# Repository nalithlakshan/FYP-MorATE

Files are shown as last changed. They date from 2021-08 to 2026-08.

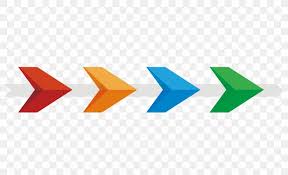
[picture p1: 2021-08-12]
QT Software Project/img/testing3.jpg

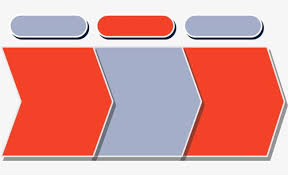
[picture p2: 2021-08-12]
QT Software Project/img/testing4.png

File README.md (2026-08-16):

# FYP-MorATE
This repository contains all the design files and the source codes of an Automated Test Equipment (ATE) for digital IC testing, developed by the final year project group-16 of the ENTC16 batch.

Youtube video link (demonstration): https://www.youtube.com/watch?v=_BMeR-ZwBSQ

Design files and source codes consist of,
* Altium PCB design projects of each individual PCB of the ATE
* QT project of the standalone computer software GUI of the ATE
* Embedded firmware projects of the STM32 microcontrollers in the ATE
* Quartus project of the FPGA digital design for the digital system in the ATE.

## Publication
L. Nawarathna, N. Udugampola, Y. Yasawardhana, T. Weerasinghe and S. Thayaparan, "Low-Cost Automatic Test Equipment for Digital ICs Using DE0-Nano - Altera Cyclone IV FPGA," 2021 3rd International Conference on Electrical, Control and Instrumentation Engineering (ICECIE), Kuala Lumpur, Malaysia, 2021, pp. 1-4, doi: 10.1109/ICECIE52348.2021.9664695.

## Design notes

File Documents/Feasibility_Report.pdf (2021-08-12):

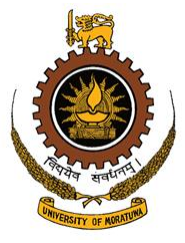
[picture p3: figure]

i

# IC Tester

### Project Proposal and Feasibility Report submitted in partial fulfillment of the

### requirements for the Degree of Bachelor of Science of Engineering in

### The Department of Electronic & Telecommunication Engineering University of

### Moratuwa

Supervisor:

Dr. Thayaparan Subramniam

Group Members:

K.G.L.P.Nawarathna

N.L.Udugampola

W.W.A.T.E.Weerasignhe

N.P.Y.Yasawardhana

ii

## Abstract

IC TESTER

Group members:

K.G.L.P.Nawarathna, N.L.Udugampola, W.W.A.T.E.Weerasignhe, N.P.Y.Yasawardhana

Department of Electronic and Telecommunication Engineering

Supervisor: Dr. Thayaparan Subramniam

Keywords: FPGA, Hardware Architecture, Integrated Circuit, IC Tester, ATE

This report acknowledges a feasibility study of designing, prototyping, and testing an IC tester.

The scope of this project basically covers development of a standalone computer software with

GUI, digital design and implementation of digital IO driving unit, hardware design of electrical

measuring instruments, power sources etc. Finally, the complete task is intended to be prototyped

and basic tests like IDDQ test, continuity test, scan test, boundary scan and etc. will be

implemented and demonstrated on digital ICs.

Current state-of-the-art in IC testing consists of very high-speed digital testing capabilities even

up to 5Gbps, highly parallel testing capabilities along with automation in all possible areas.

Teradyne, Advantest, LTX-Credence are some leading commercial vendors of Automatic Test

Equipment (ATE). Price of an ATE tester from such a vendor is millions of dollars.

Ultimate motive of this project is to start IC testing in Sri Lanka. This first step of developing a

locally made IC tester would create new business opportunities within the country. This report

emphasizes that it is feasible to continue this project

iii

## Table of Contents

iv

v

## Table of Figures

vi

## List of Tables

vii

## Acronyms and Abbreviations

IC | Integrated Circuit
VLSI | Very Large-Scale Integration
ATE | Automatic Test Equipment
DUT | Device Under Test
MCU | Microcontroller Unit
UART | Universal Asynchronous Receiver-Transmitter
USB | Universal Serial Bus
SPI | Serial Peripheral Interface
FPGA | Field Programmable Gate Array

## 1. INTRODUCTION

## 1.1 Introduction of IC Testing

Testing is a step followed in IC fabrication process to ensure the selected device has no

manufacturing defects. In earlier times, IC designers only focused about the speed, area and power

in optimization of the design. In contrast to that nowadays, testability has become the next factor

which decides the quality of a design. According to the VLSI Realization Process the testing is

placed as the process before delivering the chips to the customers.

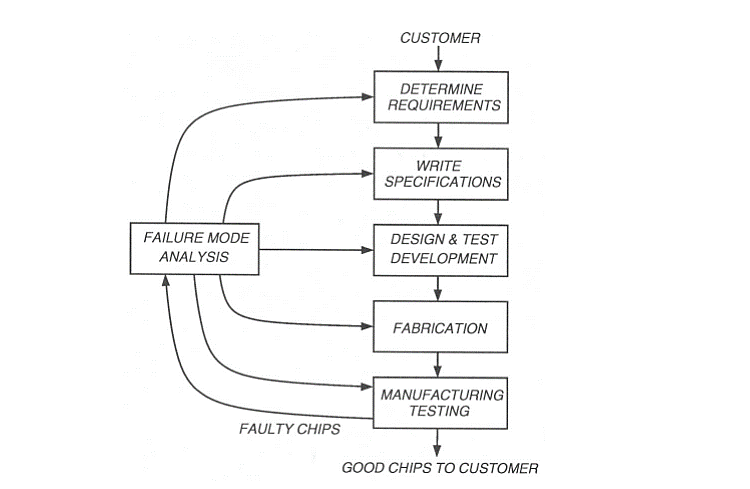
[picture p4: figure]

Figure 1-1 VLSI Realization Process

Generally, ICs are manufactured in large quantities on a single wafer by exposing to the processes

such as photolithography. Before this wafer is cut into pieces in other words which is called as die

preparation, to obtain individual circuits, all the individual circuits are tested for their functional

defects which can be occurred by activities such as misalignment of films, faults with etching

process, faults in materials and impurities. This process is known as Wafer Testing. Then, to

prevent physical damage and corrosion, the dice are placed inside a supporting case. This process

is named as IC packaging. Because there are mechanical and chemical processes involved in

packaging, even after the wafer test is completed successfully, faults in IC can occur. For example,

the bonding wires can be damaged or shorted in encapsulation, die can be misaligned and mutual inductance and capacitance can appear. Therefore, it is essential to perform tests again before

delivering good chips to the customers.

Both wafer testing and final testing after packaging are conducted by the machines called ATE.

They can perform both Parametric Tests (such as output drive current test, leakage test etc.) and

Functional Tests (check the proper functionality of chip nodes). High end testers consist of three

components which are test head, workstation, and mainframe. Workstation can be identified as the

user interface to the tester. A user can debug an IC through the software packages included in the

workstation. Mainframe serves as the unit which includes parts such as measuring instruments,

power supplies, digital driver unit etc. The test head contains more sensitive equipment which

needs less distance to the DUT. Some of the ATE machines manufactured by commercial vendors

are as follows

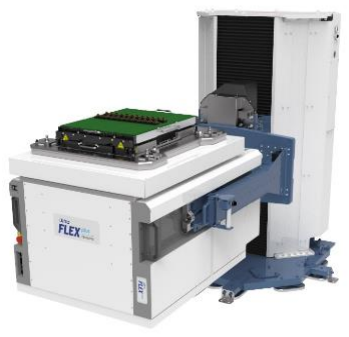
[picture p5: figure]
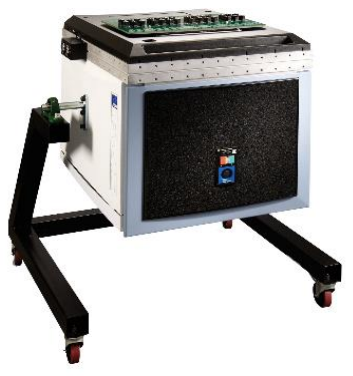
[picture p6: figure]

Figure 1-2 Teradyne UltraFLEXplus | Figure 1-3Teradyne J750Ex-HD Family
- 2.2Gbps digital performance ● 512 digital channels per instrument ● 256 Power supply channels | ● 400 Mbps digital performance ● 2048 multifunction pins ● Parallel IC testing capability
Price – Approximately $2 Million | Price – starting from $99,000

## 1.2 The Problem Statement

IC manufacturers perform tests within their manufacturing plant or outsource the chips to other

companies who carry out the procedure. Since the chips are tested by high end testers, similar to the ATE machines mentioned above, it costs a considerable amount of money for the procedure.

A company which facilitates the IC testing process can be considered as a successful business in

the silicon industry.

Currently in Sri Lanka, ATE machines are not available to perform tests for ICs. It would be an

immense opportunity for the electronic industry in the country as well as a door opening for job

market if an IC tester can be manufactured in Sri Lanka.

## 1.3 Primary Objectives

Primary objectives of this project can be listed as follows.

1. Design and prototype a low cost scaled down hardware software solution for digital IC

testing

The IC tester is expected to test the packaged digital ICs and the design is

exclusive of automatic probers and handlers. A user can program the IC tester

with the user interface provided.

2. Demonstrate the functionality with basic tests for selected packages of digital ICs

Tests such as continuity test, Iddq test and scan test are planned to be performed for

multiple IC packages i.e. DIP14, DIP16, DIP28.

3. Taking the first step to develop a Sri Lanka made IC tester

IC testers are not available in the current electronic industry in Sri Lanka.

Manufacturing such a tester can be a good business opportunity for sub-contracting

IC test process inside the country. The tester expected to develop in this project has

compromised functionality of an industrial scale tester but, with improvements in

future it can be brought out as an industrial scale IC tester.

## 1.4 Scope

There are mainly 5 areas where the scope of this project can be categorized.

1. Standalone cross platform computer software with GUI

This software provides the interface between the tester hardware and the user. It is

based on QT C++ framework, embedded SQLite Database Management System

and a USB interface with the tester hardware.

2. Embedded firmware development

Data transfer and signal control between the computer software package, digital

driver unit and pin cards are handled by the STM32 MCUs. Protocols such as

UART, USB and SPI are expected to be included in the firmware.

3. Digital design and logic driving unit

This unit will be implemented as an FPGA design with Verilog. Up to 20Mbps data

rate will be maintained in the 128 I/O ports. Maximum parallel capability will be

32 inputs and 32outputs at a time.

4. Hardware Designing and Prototyping

Multiple programmable power supply units will be included with various voltage

ranges, current limits, and resolution.

Ex: 0-5V power supply with 1.5A current limit and 10mV resolution

Programmable current source is expected to be designed for the tester. A voltmeter

with milli Volt range and a current measuring unit capable of measuring up to nano

Ampere range are included. Although the complete design will contain 16 pin

cards, for the prototype 2 pin cards will be added including the programmable

switching and routing circuitry and power and control circuitry.

5. Implementing basic tests on suitable ICs.

Following tests are planned to establish in the tester. Continuity testing, Iddq

testing, Scan testing, Boundary scan testing, Functional testing and Bypass Testing.

DIP14, DIP16, DIP28/ DIP40, SOC16, QFP/ TQFP/ LQFP48 are the IC packages

planned to be tested for demonstration.

## 1.6 Uniqueness and National Importance of the Project

The end prototype of this project will be an initiative step to design a Sri Lankan made IC tester.

Since IC testing is not currently an industry in Sri Lanka, this will be a precious opportunity to

start subcontracting in IC testing. In our scope the IC testing is expected to be performed for only packaged ICs. By designing and developing automatic probes and arms and improving the

capability this tester can elevate to wafer testing level.

One of the intentions of this project is to minimize the cost of the product. Powerful IC testers

contain high end instruments such as power supplies, voltmeters purchased and placed off the shelf

from such commercial instrument manufacturers. In our design to minimize the cost in our design,

units such as power supplies and voltmeters are designed by us. Even though it will degrade the

capability of the tester, still selected digital ICs with low complexity can be tested from our tester.

## 1.7 Potential Customers/beneficiaries

The long-term goal of this project is start IC testing in Sri Lanka. The end product of this project

can be considered as the first leap of IC testing in the country and with the time being by adding

sufficient amount of equipment and knowledge, a commercial IC testing service can be formed in

Sri Lanka.

This IC tester can also be sold in the market as a commercial product specially for part suppliers

who handle low quantity custom made ICs and low volumes of FPGA chips programmed with

custom digital designs.

E.g. oscilloscope manufacturers, telecommunication equipment manufacturer.

Additionally, it is possible to market the product as a test bench for electronic research and

development, repair and maintenance. Electronic sign engineers can be considered as an example

for this customer base.

## 2. LITERATURE REVIEW

## 2.1 Generic Architecture of State-Of-The-Art IC Testers

Automated Test Equipment (ATE) are widely used in the semiconductor industry for

manufacturing testing of ICs. Some popular commercial vendors of ATEs are Teradyne, LTX-

Credence, Advantest, etc.

A high-performance tester with a fully upgraded configuration may cost around two million dollars

in average. Targeting only s specific class of devices with designs for testability, a test system with

a reduced configuration can be bought for a price as low as hundred thousand dollars. Probers and

handlers which handles the automation of picking, placing and probing may cost about half a

million dollars additionally.

### 2.1.1 Major Components of High-end ATE testers

- Test head
- Workstation
- Mainframe

Workstation is the computer providing a

user interface to the tester. Test programs are

written, executed and debugged from the

workstation with the tools provided by ATE

vendor. When tester is used in a production

line, workers can control and monitor its day-

to-day operations using the workstation.

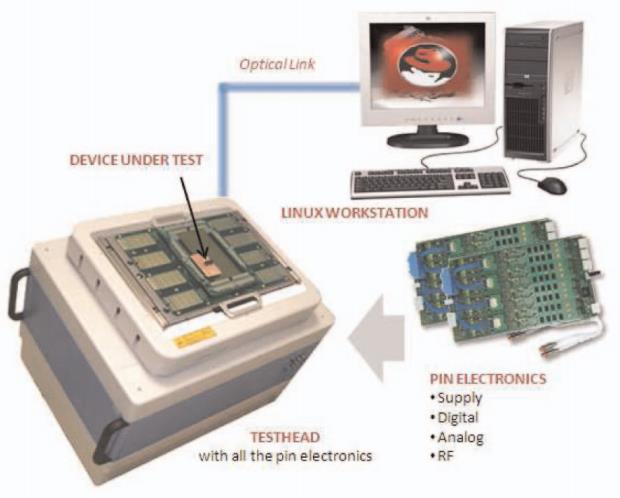
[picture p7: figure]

Mainframe consists of all the major internal hardware of the tester such as measuring instruments,

power supplies, current sources, loads, switching and control circuitry, etc. It normally has separate

subsystems for dc power, digital testing, analog testing, etc. It may also have a robotic manipulator

for positioning of the test head. Normally a refrigeration system providing coolants to regulate the

temperature is also there.

Test head contains highly sensitive test equipment that require close proximity to the device been

tested. Mostly the measuring instruments that need to be right at the pins or pads of the device

Figure 2-1 Major Components of an ATE tester under test (DUT) are there in test head. For example, digital I/O data streams with high speed

require shorter electrical paths between the I/O pins of the DUT and the IO driving ports of the

tester. That is why digital drivers of ATE testers are normally located in the test head.

### 2.1.2 DUT Interfacing

Device Interface Board (DIB) provides electrical connections between the ATE and the DUT.

Depending on the ATE vendor’s technology some other names are also commonly used for the

DIB such as swap block, performance board, family board, etc. Shape and size may differ from

DIB to DIB, but all of their main purpose is to provide a socketed electrical connection between

the test instruments of the ATE and the pins or pads of the DUT.

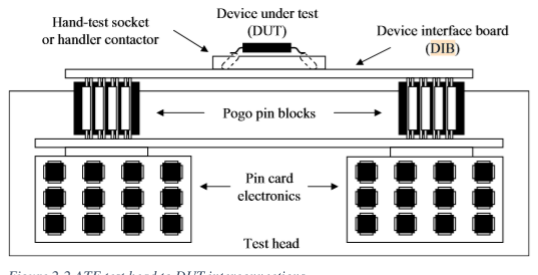
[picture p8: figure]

Following Alternative methods are also used in interfacing the ATE with the DUT.

- Wafer Probers
- Handlers (for packaged devices/ ICs)
- Focused Ion Beams
- Focused Temperature Systems, etc.

### 2.1.3 Tester Hardware Architecture

ATE comprised of following hardware units.

- General purpose voltage/current sources
- Voltage, current measuring instruments
- Switching matrices
- Digital pin cards

Figure 2-2 ATE test head to DUT interconnections

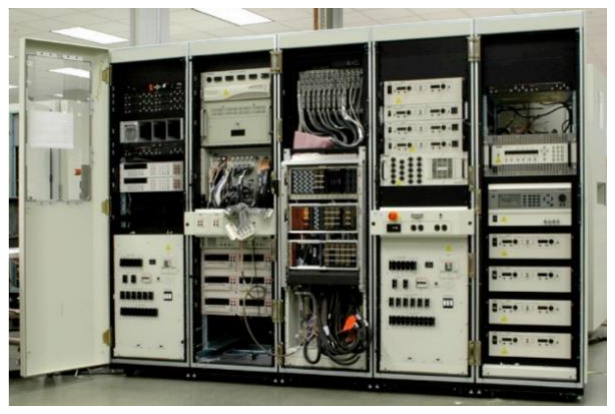
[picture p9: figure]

Figure 2-3 Hardware inside an ATE

- Arbitrary waveform generator and waveform digitizer
- Time measurement system
- RF subsystem
- Computing hardware

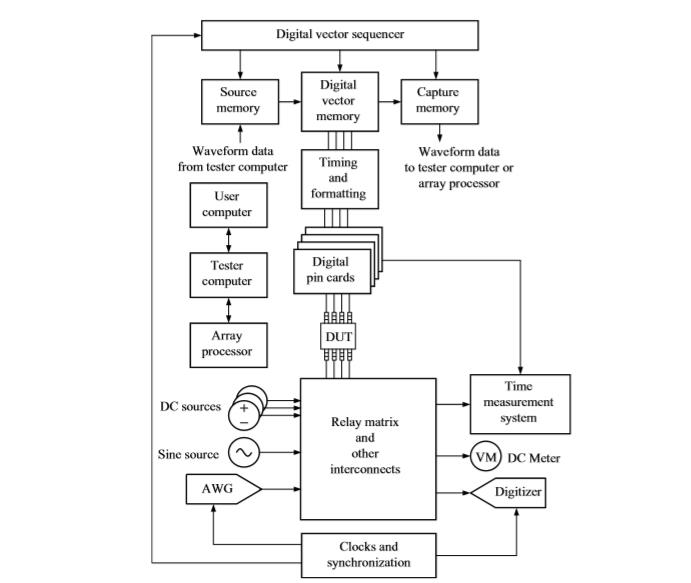
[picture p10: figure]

### 2.1.4 Test Flow

Following diagram shows a general flow chart of testing an IC which starts with continuity testing.

The continuity check simply measures the voltage across the protection diodes of the DUT pins,

by forcing a small current, in order to make sure that the DUT is well connected to the tester. Then

one after another different functional tests, DC tests, AC tests, digital tests are performed to the IC

Figure 2-4 Generic ATE architecture being tested. In each stage if a test is failed the IC is rejected. Both good and bad ICs are sorted in

to bins.

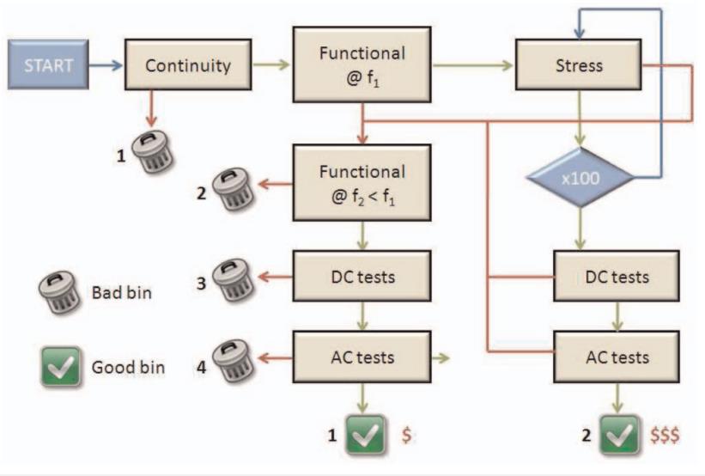
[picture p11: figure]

Figure 2-5 Example of Test Flow

## 2.2 Alternative Methodologies of Testing

Apart from high-end ATE testers used in manufacturing testing in IC fabrication, there are other

methodologies which can be used to test ICs but with different purposes like below.

- Test equipment for manually performed electronic test and repair (mainly for PCBs,

soldered components)

- Combinational logic level handheld IC testers and IC detectors

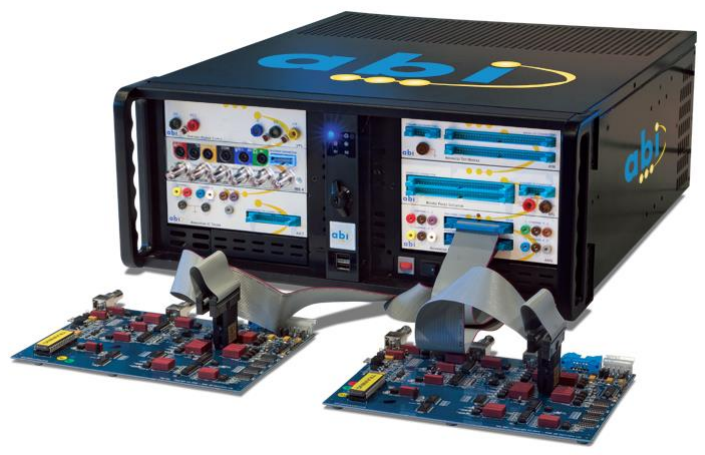
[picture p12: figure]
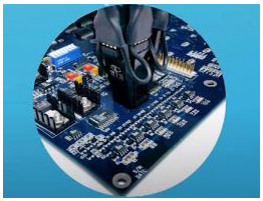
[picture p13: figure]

Figure 2-6 Probing soldered components for testing | Figure 2-7 PCB testing test equipment for R&D purposes

Following figure shows how testing R&D purposes is performed in an industrial environment.

A test module aimed

at testing all digital

ICs and PCBs from all

logic families.

Multiplex matrix

switch with a

16x16 switch

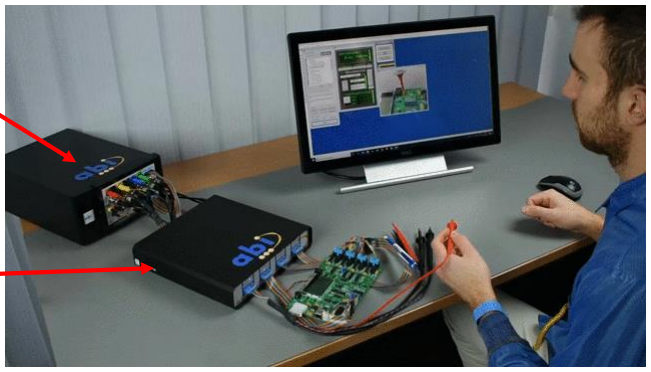
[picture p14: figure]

matrix interface | Figure 2-8 R&D Level Testing

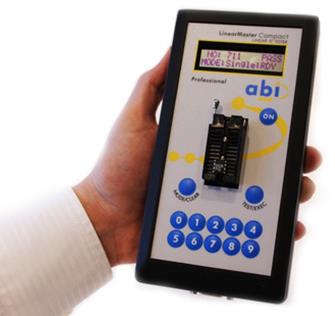
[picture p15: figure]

Figure 2-10 A hand-held IC Tester

This picture shows LinearMaster Compact

Professional by Abi Electronics which is a

handheld IC tester which can do simple logic

testing for ICs with up to 16 pins. It has a large

embedded database to detecting unknown ICs as

well.

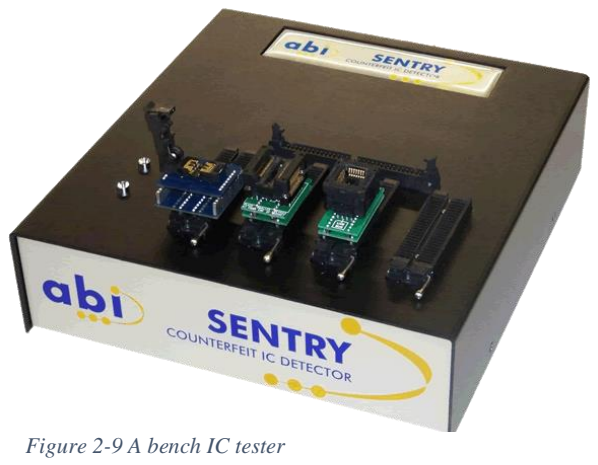
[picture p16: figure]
Figure 2-9 A bench IC tester

Sentry Counterfeit IC Detector by Abi

Electronics is a larger version of the previous

one which has 256 test channels. Apart from

identifying unknown ICs it can easily detect

missing or incorrect dies, lack of bond wires,

inaccurate pinouts and pin impedance

variations. Simple pass or fail results are

returned after testing.

## 3. METHODOLOGY

## 3.1 Project Architecture

### 3.1.1 Block Diagram

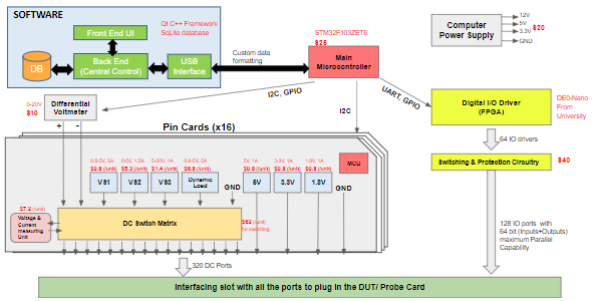
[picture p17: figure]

IC Tester Software is developed as a stand-alone desktop application using Qt framework with

backend in C++ language. Moreover, this software is the top level of the control hierarchy of the

IC tester. Front end UI is made as a Qt widget application. In the backend, the input data from the

user interface which are recorded in the database are converted to a format comprehensible by the

main microcontroller. SQLite is used as the DBMS for this desktop application. USB serial

communication is used to communicate between the desktop application and the STM32

microcontroller.

Main Microcontroller (STM32F103VET6) is the main control unit inside IC tester hardware. It

retrieves commands from the computer software via USB serial communication and then the

received data packets are decoded in order to understand the commands. Then according to those

commands, the main microcontroller delegates tasks to each individual hardware units of the

whole tester.

Figure 3-1 Block diagram of the project architecture

Digital I/O Driver, protection and switching circuitry is the digital subsystem of the tester

which mainly consists of 2 FPGAs, one for sourcing digital data to input pins of the DUT and the

other for capturing digital data from output pins of the DUT. These two FPGAs have 32 digital

drivers each which make the maximum parallel capability of the tester up to 32 bit. Furthermore,

the FPGAs have the ability to change the clock speed as desired.

The interfacing I/O pins of the FPGA goes through protection and switching circuitry. A single

I/O driver is connected to 2 digital I/O ports of the tester via relays, one with 3.3-5V logic

conversion.

Pin cards used in the tester are pluggable based on the requirement where 16 such cards are used

in total having 20 DC interfacing ports each. Hence the total number of ports of the IC Tester sums

to 320 ports. Out of the 20 DC pins in each pin card, 16 pins are multipurpose because they are

switchable through a DC switch matrix and the other 4 pins are directly connected to fixed voltage

sources. Voltage and currents of each individual pin can be measured with the voltage and current

measuring unit in each of the cards. All the relays, multiplexers and shift registers are controlled

with a dedicated MCU in the pin card which also communicates with the main MCU of the IC

Tester.

Differential voltmeter is common to all the 16 pin cards so that it can measure voltage between

any 2 ports out of 320 ports in the IC tester.

### 3.1.2 Flow Chart

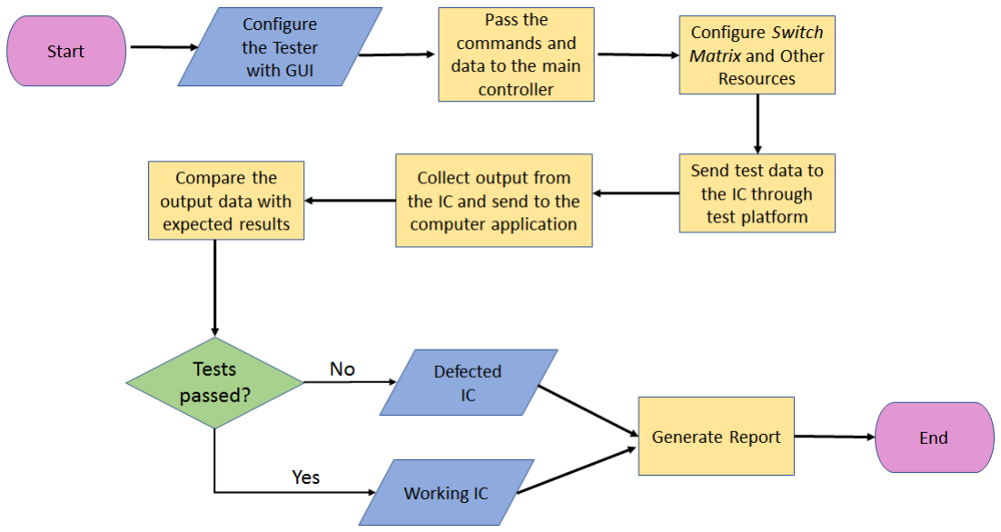
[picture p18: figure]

Figure 3-2 Flow chart of the project architecture

## 3.2 Evaluation of Alternative Methodologies

IC Tester Software framework alternatives

Being more hardware related and more of on-site testing, a standalone desktop application is more

suited than a web or mobile application. Out of the following frameworks suitable for developing

standalone applications, Qt was selected.

Alternative | Pros | Cons
Qt (C++) | Cross-platform C++ more supportive for hardware High community support Better GUI designer, being faster than other languages Good documentation | Complexity to the build process
.Net (C#) | Reliable and simple caching system Large community | Mainly used in windows Memory leaks Limited object-relational support
JavaFX (Java) | Cross-platform Open source Java being the most popular programming language in the world | Not quite mature enough Not very supportive for hardware related projects Comparatively low Performance

Table 1 Alternatives for desktop application frameworks

DBMS alternatives

Out of the following options, SQLite was selected being a serverless (embedded) database that

runs as a part of the application.

Alternative | Pros | Cons
SQLite | Lightweight in setup, administration, and required resource Embedded, server-less database Best suited for standalone apps, specially Qt widget applications | Comparatively smaller library size
PostgreSQL, MySQL | The world’s most advanced open source database Improved security | Requires a DB server Difficult to setup with Qt compared to SQLite

Table 2 Alternatives for Database Management Systems

Power supply units

In making power supplies in the IC tester, we decided to proceed with making our own power

supplies due to the low cost and flexibility.

Alternative | Pros | Cons
Use industrial grade power supplies ($1200 per unit) | High precision and high reliability Wide range of operation Functionality can be monitored through a network | The range of operations exceed the limits of our design. The cost over number of configurable channels is too high.
Use power supply modules | Voltages and currents can be programed | The range of operations exceed the limits of our design. Low programmability
Designing our own Power supplies | Can be designed to match the desired requirements. | Can have design errors.

Table 3 Alternatives for power supply units

Digital I/O driver

Due to the cost effectiveness, we decided to implement our own design with FPGA.

Method | Advantages | Disadvantages
Use source and capture modules | High data rates (ex: 200 MHz) Widely programmable IO levels Built in pattern generators | The cost of a single module is too high (32 bidirectional channel, 2 logic voltage level modules with 10MHz clock -$1600)
Implement our own design with FPGA | Available in the university for initial testing | Limited embedded memory Protections methods are not available for pins (ESD, over voltage, over current)

Table 4 Alternatives for digital I/O drivers

## 3.3 Risk Analysis

Risks | How to overcome?
Limitation of affordable shipping methods due to Covid-19 | Order components from the same supplier, together with the other groups to share shipping cost.
Inability to get together due to Covid-19 | Using online collaboration platforms as much as possible. Ex: Zoom, Atom Teletype, EasyEDA, etc.
Hardware design faults lead to huge additional costs and time. | Every hardware design task is carried out with the collaboration of at least two members. Choosing components by carefully going through datasheets of number of suitable candidates. Going through thorough design verifications.

Risk of a selected component being out of stock

Keep alternative components selected.

Choosing components which are available with 2 selected suppliers (Digi Key, LCSC)

Common resources with the university being unavailable due to other utilizations.

Communication with the relevant labs and do reservations based on requirement.

Table 5 Risk Analysis

## 3.4 Resource requirements and budget

Cost Categories | Total Cost (2 pin card)
Device power supply and wiring | $40
Programmable Power Supply units of the tester | $34
Hardware for switching & routing with a DC matrix | $123
Voltage & Current Measuring Instruments | $31
Hardware for Digital I/O System | $32
Passive Components | $20
Enclosure Cost | $30
PCB cost | $40
Shipping cost | $384
TOTAL | $734

Table 6 Total budget of the project

Since our project is very hardware intensive, electronic components were selected from two

different suppliers (DIGI Key and LCSC) and the budget was prepared mainly with the quotations

of those electronic components which are listed below.

Manufacturer | Man. Part No | Qty | Unit Price | Cost
On Semi | NTMFS4C022NT1G | 17 | $0.261 | $4.437
Omron Electronics | G5NB-1A-E-DC12 | 142 | $0.250 | $35.500
TE Connectivity | 1649222-1 | 36 | $0.350 | $12.600
Texas Instruments | ULN2003A | 24 | $0.120 | $2.880
On Semi | 74HC595 | 24 | $0.114 | $2.736
On Semi | MMBT2222ALT1G | 17 | $0.009 | $0.153
ST Microelectronics | STM32F103C8T6 | 1 | $2.000 | $2.000
Texas Instruments | CD74HC4067SM96 | 3 | $0.470 | $1.410

$61.716

Total for 2 pin cards | $123.43

Table 7 Budget for the major components for DC switching and routing

Manufacturer | Man. Part No | Qty | Unit Price | Cost
Omron Electronics | G5NB-1A-E-DC12 | 8 | $0.250 | $2.000
TE Connectivity | 1649222-1 | 4 | $0.350 | $1.400
Maxim Integrated | MAX4239AUT | 2 | $1.000 | $2.000
Texas Instruments | ADS1115 | 3 | $3.170 | $9.510
Texas Instruments | LMV321 | 2 | $0.170 | $0.340
Texas Instruments | ISO1541DR | 2 | $1.170 | $2.340
Analog Devices (https://lcsc.com/brand-detail/178.html) | REF02CSZ-REEL7 | 2 | $2.081 | $4.162
Analog Devices (https://lcsc.com/brand-detail/178.html) | OP1177 | 4 | $1.547 | $6.118
Texas Instruments | TPL0102 | 2 | $1.760 | $3.520
| | | | $31.390

Table 8 Budget of the major components for measuring instruments and dynamic loads

Manufacturer | Man. Part No | Qty | Unit Price | Cost
Texas Instruments | TPS56528DDAR | 2 | 0.59 | 1.18
Analog Devices | LT3081 | 2 | 5.32 | 10.64
Texas Instruments | TPS54202 | 2 | 0.39 | 0.78
Texas Instruments | TPS7A7001DDAR | 6 | 0.77 | 4.62
Texas Instruments | TPL0102-100RUCR | 10 | 1.417 | 14.17
SXN | HSMS0650-3R3M | 2 | 0.21 | 0.42
TDK | RLF7030T-6R8M2R8 | 2 | 1.009 | 2.018
| | | | $33.828

Table 9 Budget of the major components for power sources

## 3.5 Task Delegation

Preliminary tasks | Digital design and
implementation
Hardware design | Software and
firmware
development

Testing and
prototyping
Task | Nalith | Yasara | Thilina | Lahiru

Literature review and exploring possible methods

Designing programmable power supply units

Designing voltage and current measuring instruments

Designing a programmable dynamic load

Design of hardware for switching and routing in the tester

Hardware design of Digital I/O subsystem

PCB design

Front end software development (standalone GUI)

Backend software development and database management

Communication Interface between the PC and Tester

Firmware development

Digital design of digital I/O subsystem on a FPGA

Hardware prototyping with wiring, soldering, etc.

Electronic testing & debugging of prototypes

Software & firmware testing of prototypes

Documentation

Table 10 Task delegation among the group members

There are 4 major categories of work in the project and all 4 members take part in tasks from all

those 4 categories, for better efficiency and productivity. But major contributions of the members

can be summarized as, Nalith and Yasara more focused on firmware development, software

switching and control while Thilina and Lahiru contributing more for hardware and digital design.

## 3.6 Timeline

Task | Feb | Mar | Apr | May | Jun | Jul | Aug | Sep | Oct | Nov | Dec

Literature review and exploring possible methods

Designing programmable power supply units

Designing voltage and current measuring instruments

Designing a programmable
dynamic load

Design of hardware for switching and routing in the tester

Hardware design of Digital I/O subsystem

PCB design

Front end software development (standalone GUI)

Backend software development and database management

Communication Interface
between the PC and Tester

Firmware development

Digital design of digital I/O subsystem on a FPGA

Hardware prototyping with wiring, soldering, etc.

Electronic testing & debugging of prototypes

Software & firmware testing of prototypes

Documentation

Table 11 Timeline

## 3.7 Initial Results

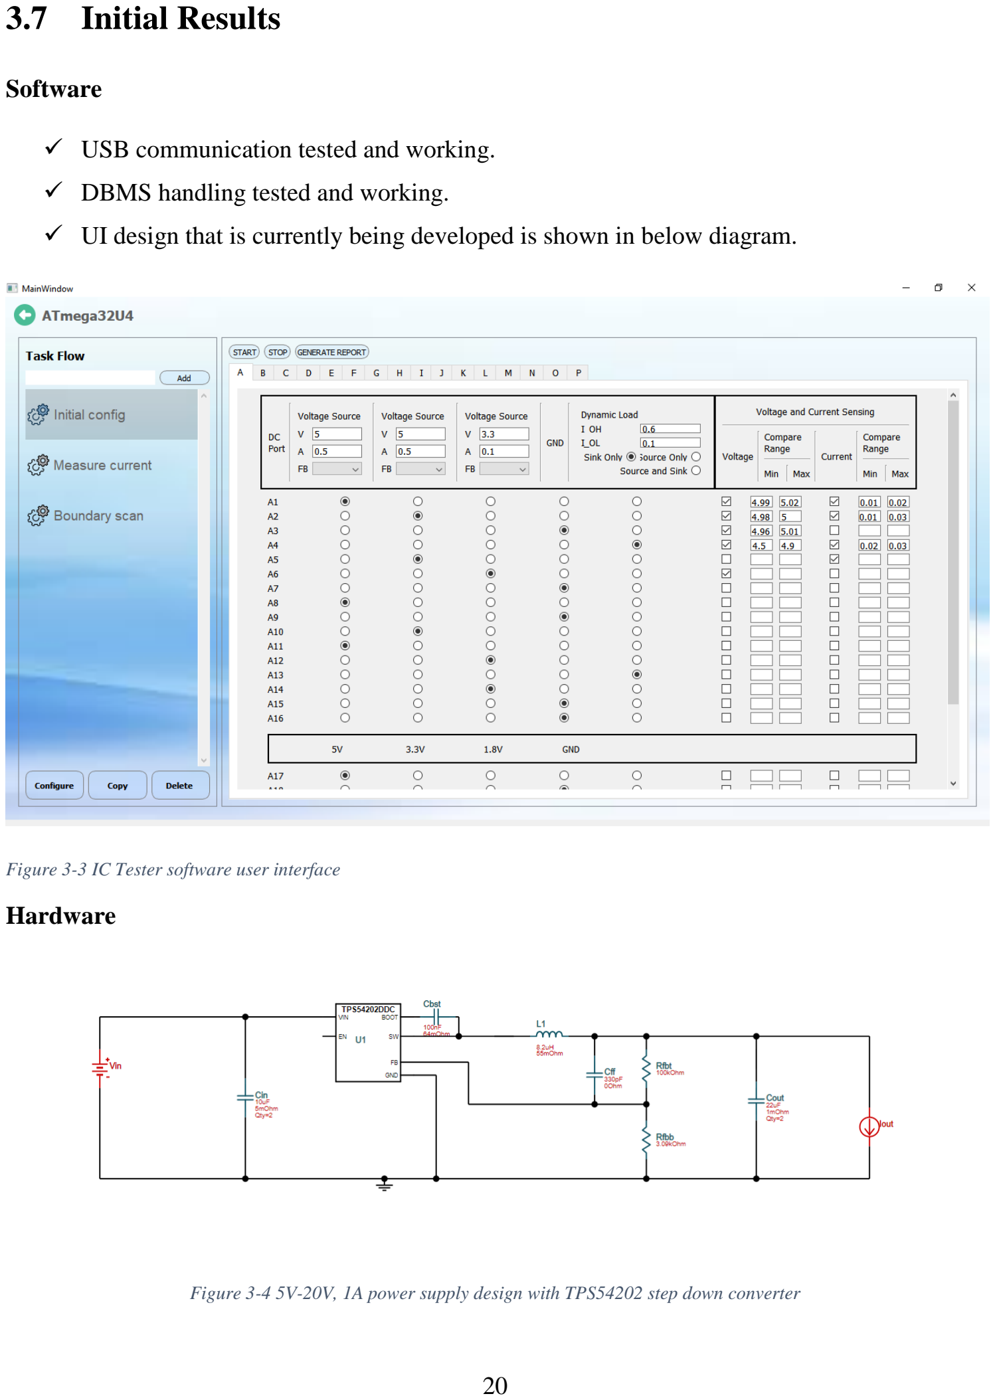
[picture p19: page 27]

Software

✓ USB communication tested and working.

✓ DBMS handling tested and working.

✓ UI design that is currently being developed is shown in below diagram.

Figure 3-3 IC Tester software user interface

Hardware

Figure 3-4 5V-20V, 1A power supply design with TPS54202 step down converter

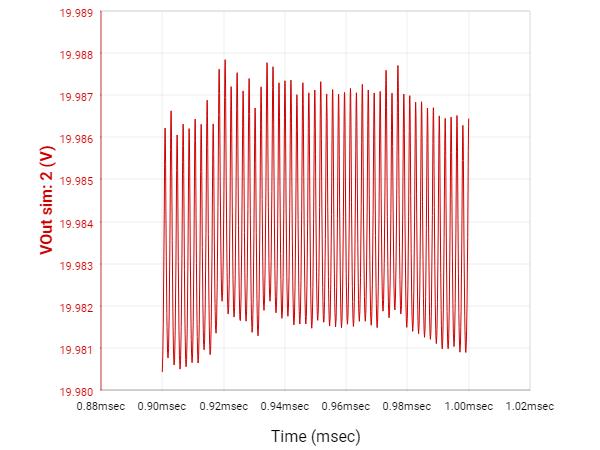
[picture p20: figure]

Figure 3-5 Steady state simulation results for power supply design with TPS54202 step down converter

## 4. DISCUSSION AND CONCLUTION

## 4.1 Main findings of the literature survey

The Literature survey was mainly carried out in three stages. On the first stage, we analyzed the

production cycle of Integrated Circuits (ICs) and the importance of IC testing during the

production. It was reviled that the testing is done in two production stages which are after the wafer

(die) is produced and after the IC is packaged. Through these tests, ICs with manufacturing defects

are identified. Further, functional ICs are categorized into several grades based on their

performance. Since our scope only extends to testing packaged ICs, we mainly focused on

identifying the manufacturing faults that occur during the packaging stage such as die

misalignments, shorted or missing bonding wires and mutual inductance between bonding wires.

Further, we analyzed the electrical tests that we can carry out to identify such defective ICs and

also selected the types testes and determined complexity of each test that we are going to

implement in our design within the scope of the project.

On the second stage of the literature survey, we were mainly focused on the hardware architecture

of a generic IC tester. On the top level, an IC tester is a collection of discrete hardware units which

functions as a power source or a data sourcing/capturing device or measuring device. These

individual units are controlled by a central processing device to perform the tests which are pre-

programmed by the user. It was identified that every IC tester regardless of its performance and

capabilities, must contain at least one hardware unit of these three categories. The number of

individual hardware units, the capabilities of each unit and the processing capability of the tester

defines the types of tests and the complexity of each test that it can perform. With that knowledge,

we calculated the resource requirements to implement the tests which we selected in stage one and

then determined the number of hardware units and the specifications of each unit.

On the third stage of the literature survey, we reviewed and analyzed the existing IC testers

available in the market. It was identified that there are three different kinds of testers available in

the market targeting different sectors. IC testers for IC suppliers are the most expensive and most

complex type of testers. They are produced in very small quantities and they are highly

customizable. The second kind of testers is aimed at the research and development sector. They are less expensive, less complex but more user friendly. Apart from testing ICs, they can be used

as test benches to test electronic products and assembled PCBs. The third kind of testers is aimed

at electronic repairing sector. They are the least complex testers and they perform very basic tests

on a limited range of ICs. These testers are mostly used in electronic repair shops.

Since our project is focused on testing packaged ICs for manufacturing faults, we further looked

into the hardware design of such IC testers. It was reviled that all of those testers use industrial-

grade rack-mounted powers supplies and multimeters from reputed third party manufactures for

its power and measuring units while using their own technology to design data source/capture

devices. It was further noticed that the usage of such third-party modules largely increases the

overall cost of the IC tester. With that knowledge, we thoroughly analyzed the available solutions,

technologies and methods to implement the required hardware resources that we selected in stage

two. After analyzing all the alternatives, it was found that to meet the specifications of each

hardware unit while maintaining the coverall production cost at a minimum, it is required design

and prototype all hardware units by ourselves.

## 4.2 Feasibility of the Project

### 4.2.1 Technical Feasibility of the Project

The technologies we are going to use in the project are neither very new nor cutting-edge. In terms

of software development, it is required to develop a GUI for the IC tester, implement the

communication between the computer and the embedded controller and program the embedded

controller. We planning to achieve these tasks using the QT framework and C++ which are widely

used for similar tasks and has great community support. In terms of hardware development, we

are mostly working in the low and mid-frequency analogue electronic domain. We have already

learned all the required fundamental knowledge from the course modules. It is required to develop

several PCBs, assemble and test them. We are planning to use the student versions of Altium

designer which is available at the university to design the PCBs and to use the soldering stations

in the electronic workshop to assemble the PCBs. For testing and calibration of the PCBs, the

equipment available in the university laboratories such as oscilloscope and bench multimeter is

sufficient. Considering the above facts, we can consider that the project is technically feasible.

### 4.2.2 Financial Feasibility of the Project

The project is not sponsored by and external party and it is fully funded by the contribution of the

four members of the group. We initially plan to contribute Rs. 35,000 per head. The roughly

estimated budget for the project considering many worst-case scenarios totals to $1893 for the full

design. But the design is modular and scalable since it has many repairing hardware components.

The full design of the tester has 16 pin cards which result in 256 test channels. However, it was

found that, for the demonstration purposes, only two pin cards which offer 32 test channels is

sufficient. It would bring down the project cost to $730 which is within our initial budget. It is

noticeable that about ⅓ of the total project cost comes from the shipping charges for PCB and

electronic components. However, we are looking forward to combining PCB and component

orders with other groups where we can share shipping charges which ultimately reduce the project

cost. We are also looking forward to utilize university resources as much as possible to bring down

the total project cost.

### 4.2.3 Social Feasibility of the Project

The ultimate goal of this project is to take the first step forward to design a low-cost IC tester

which is to be fully assembled in Sri Lanka and subcontract IC testing for international electronic

component suppliers. This is a very low quantity product. The users of this IC testers would be a

small fraction of the society who are will be owning, operating or repairing these testers. Apart

from those who particularly have an interest in IC testing, there will not be any significant effect

on the general public caused by launching this product. Therefore, it can be considered that the

project is socially feasible.

## 4.3 Impact of the Project

### 4.3.1 Local Impact of the Project

IC testing is an essential and unavoidable step in IC manufacturing. Therefore, it has a growing

market. But IC testing is currently centered around the developing countries. The main obstacle

which prevents a developing country like Sri Lanka entering the IC testing industry is mainly due to the high cost of the IC testers which extends beyond a million dollars per single machine. The

main objective of this project is to develop a low-cost IC tester which can be afforded by Sri

Lankan companies and start subcontracting IC testing for electronic component suppliers. This

will expose Sri Lanka to a new market segment in the electronic industry while creating tons of

new job opportunities. These IC testers will require electronic test engineers to develop tests and

program the testers. In the long run, it will be possible to introduce new engineering field which

focused on electronic testing.

### 4.3.2 Global Impact of the Project

The introduction of a Low - cost IC tester from Sri Lanka which can be used to test ICs after

manufacturing will urge other countries to develop similar products. With many countries entering

into the IC testing market will be able to provide significant competition to the current IC testing

market which is centered around the developed countries. Testing cost takes about 30 to 40% of

the IC’s market value. With the integration of low-cost testers, it is possible to decrease testing

cost which will ultimately reduce selling prices of ICs making them more affordable.

## 4.4 Conclusion

Looking at the discussion of feasibility and significance, it is evident that the project is feasible

within the selected scope. All the technologies which will be used in the project are wildly used

and proven to work. The project can highly utilize the resources available in the university.

Although the project is not backed by any third party, the estimated cost of the project considering

many worst cases does not exceed the available budget. Further, At the end of the feasibility

presentation, the ENTC staff, a group of highly experienced and reputed academics agrees that the

project is feasible in all aspects and complex enough as a final year project. Being the first step to

exposing Sri Lanka to the IC testing industry which will result in many new job opportunities, this

project has a large local and global impact. Therefore, we arrive at our conclusion which is, design

and prototyping a Low-Cost IC Tester is a highly feasible and a globally and locally significant

project to be chosen and carried out as a final year project of the Department of Electronic and

telecommunication engineering.

## REFERENCES

[1] Bushnell, M. L., & Agrawal, V. D. (2002). Essentials of Electronic Testing for Digital

Memory and Mixed Signal VLSI Circuits. Kluwer Academic Publishers.

[2] Gordon, R., taenzler, F., & Burns, M. (n.d.). An Introduction to Mixed-Signal IC Test and

Measurement. Oxford University Press.

[3] Li, J.-F. (n.d.). Microsoft PowerPoint - ch01. Retrieved from

http://www.ee.ncu.edu.tw/~jfli/test1/lecture/ch01

[4] sqlite_overview. (n.d.). Retrieved from tutorialspoint:

https://www.tutorialspoint.com/sqlite/sqlite_overview.htm

[5] Thayaparan, D. (2020, January). EN4603- Digital IC Design Module Notes.
[6] UltraFLEXplus, The World’s Leading SoC Device Test Platform. (n.d.). Retrieved from

Teradyne: https://www.teradyne.com/products/ultraflexplus/

[7] Zhi, L. (2016). Qt5 C++ GUI Programming Cookbook. Packt Publishing Ltd.

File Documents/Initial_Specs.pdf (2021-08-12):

## Digital IC Tester : Initial Specifications

Power Supply Specifications
Initial plan is to make 3 independent power supply units which makes the IC tester capable of creating 3 voltage levels at the same time. Those 3 power supplies are planned to be as follows,

1A Power Supply (Qty :2)
Supply Voltage Range | : 0V (MIN) - 5V (MAX)
Supply Voltage Resolution (Step Size) | : 0.01V
Supply Current Maximum | : 1.1A
Overcurrent Protection | : Yes

6A Power Supply (Qty :1)
Supply Voltage Range | : 0.6V (MIN) - 5V (MAX)
Supply Voltage Resolution (Step Size) | : 0.1V
Supply Current Maximum | : 6A
Overcurrent Protection | : Yes

Digital I/O Specifications
Initial plan is to make 8 logic transceivers that can be configured as digital inputs/outputs or clock sources which makes the IC tester capable of using up to 8 digital/clock pins at the same time. In order to handle more pins those transceivers should be multiplexed over time.
Logic High Voltage | : 0.6V (MIN) - 5V (MAX)
Logic Low Voltage | : 0.6V (MIN) - 5V (MAX)
Logic Voltage Resolution (Step Size) | : 0.1V
Digital I/O Source Current Maximum | : 50mA
Digital I/O Sink Current Maximum | : 50mA
Frequency (bit rate) Range | : 1Hz (MIN) - 2MHz (MAX)
Frequency Resolution (Step Size) | : 1Hz (MIN)

Pin Bed for the Device Under Test
Pin bed is the slot to plug in a breakout board consisting of a holder for the IC being tested.
Maximum number of pins | : 256

Following units are placed to take measurements right at the pins,

1 current measuring unit (multiplexed with 16 pins)
Maximum Measurable Current | : 6A
Current Measuring Resolution (Step Size) : 1uA (MIN)
Current Measuring Accuracy | : ±1%

1 voltage voltage measuring unit (multiplexed with 16 pins) Voltage Measuring Resolution (Step Size) : 0.01V (MIN)
Voltage Measuring Accuracy | : ±1%

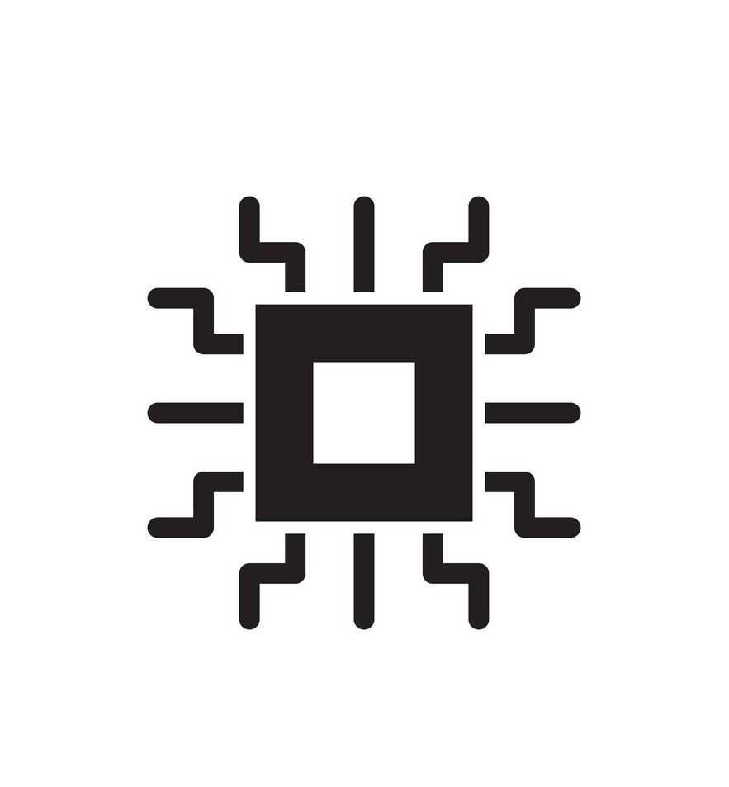
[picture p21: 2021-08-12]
QT Software Project/img/IC_img.jpg

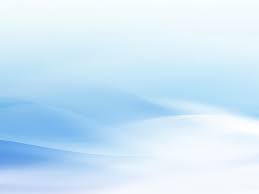
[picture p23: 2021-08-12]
QT Software Project/img/light_blue.jpg

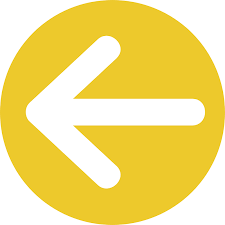
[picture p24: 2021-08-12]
QT Software Project/img/yellow_arrow.png

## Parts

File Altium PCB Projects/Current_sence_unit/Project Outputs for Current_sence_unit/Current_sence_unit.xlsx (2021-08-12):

Comment | Designator | Footprint | Quantity | Manufacturer | Manufacture Part Number | Supplier | Supplier Part Number
100nF | C1, C2, C4, C5, C7, C8, C10, C11, C12, C19, C20 | CAPC1608X09N | 11 | YAGEO | CC0603KRX7R9BB104 | LCSC | C14663
4.7uF | C3, C9, C14, C15 | CAPC1608X09N | 4 | Samsung Electro-Mechanics | CL10A475KP8NNNC | LCSC | C1705
20pF | C6 | CAPC1608X09N | 1 | YAGEO | CC0603JRNPO9BN200 | LCSC | C105621
1uF | C13, C17 | CAPC1608X09N | 2 | Samsung Electro-Mechanics | CL21B105KBFNNNE | LCSC | C28323
22uF | C16, C21 | CAPC1608X09N | 2 | Samsung Electro-Mechanics | CL10A226MP8NUNE | LCSC | C86295
10uF | C18, C22 | C0805 | 2 | Samsung Electro-Mechanics | CL21B106KOQNNNE | LCSC | C95841
S4B-XH-A (LF)(SN) | CN1, CN2 | CONN-TH_S4B-XH-A (LF)(SN) | 2 | JST Sales America | S4B-XH-A (LF)(SN) | [NoParam], LCSC | C157925
Green LED 0603 | D1, D5, D6, D7, D8, D9, D10, D11 | 0603LED_GEN | 8 | Orient | ORH-G36G | LCSC | C205443
Red LED 0603 | D2 | 0603LED_GEN | 1 | Everlight Elec | 19-217/R6C-AL1M2VY/3T | LCSC | C72044
CUS08F30,H3F | D3, D4 | PCB-7qpkjsjx5cjbarp1o0hc-1 | 2 | TOSHIBA | CUS08F30,H3F | LCSC | C150183
SN74HC595D | DD1 | PCB-72k1vk0k27b6qyyenbg0-1 | 1 | Nexperia | 74HC595D,118 | LCSC | C5947
header 2x1 | J1, J2 | PCB-55llon6gpk2h6a06nz0l-1 | 2
DB126V-5.0-2P-GN | J4, J6, J7, J9 | PCB-kiok1jlp9o9fcwf1wwvf-1 | 4 | DIBO | DB126V-5.0-2P-GN | LCSC | C395849
JST S6B-XH-A | J5 | JST S6B-XH-A | 1 | JST Sales America | S6B-XH-A(LF)(SN) | LCSC | C157919
CN-1P-M-R3 | J8, J11 | JST-S3B-XH-A(LF)(SN)_V | 2 | JST Sales America | S3B-XH-A(LF)(SN) | LCSC | C157928
ATX Connector-2x3 | J10 | 30300060 | 1 | BOOMELE(Boom Precision Elec) | 5557-2*3AW | LCSC | C54904
3A Relay | K1, K3, K4, K5, K6, K7, K8 | PCB-ei6nokn2irsc2a7yt94x-1 | 7 | Omron Electronics | G5NB-1A-E-DC12 | LCSC | C225714
5A Relay | K2 | PCB-ei6nokn2irsc2a7yt94x-1 | 1 | HF(Xiamen Hongfa Electroacoustic) | HF46F/12-HS1 | LCSC | C3636
100 | R1, R2, R3, R14, R17, R27, R28, R31 | gen0603-2 | 8 | UNI-ROYAL(Uniroyal Elec) | 0603WAF1000T5E | LCSC | C22775
24k | R4 | gen0603-2 | 1 | PANASONIC | ERJPB3B2402V | LCSC | C413706
75k | R5 | gen0603-2 | 1 | PANASONIC | ERJPB3B7502V | LCSC | C413688
1k | R6, R22 | gen0603-2 | 2 | PANASONIC | ERJPB3B1001V | LCSC | C193680
4.7k | R7, R8, R15, R16, R21, R34, R35, R36, R37, R38, R39, R40, R41, R42 | gen0603-2 | 14 | YAGEO | RC0603FR-074K7L | LCSC | C99782
10k | R9, R24 | gen0603-2 | 2 | Walsin Tech Corp | WF06Q1002BTL | LCSC | C305259
20 | R10, R11 | PCB-p5gaxfzqzpvl2g018b4o-1 | 2 | Multicomp | MCWF08U20R0BTL | LCSC | C241306
0.01 | R12 | RESC3116X07M | 1 | YAGEO | PE1206FKE470R01Z | LCSC | C364375
0.001 | R13 | RESC3116X07M | 1 | Ever Ohms Tech | MA120610FR001SZ | LCSC | C429334
10k | R18, R32 | gen0603-2 | 2 | YAGEO | RC0603FR-0710KL | LCSC | C98220
51k | R19, R20, R25, R26 | gen0603-2 | 4 | PANASONIC | ERJPB3B5102V | LCSC | C413694
39.2k | R23 | gen0603-2 | 1 | PANASONIC | ERA3AEB3922V | LCSC | C491129
42k | R29, R30, R33 | gen0603-2 | 3 | UNI-ROYAL(Uniroyal Elec) | 0603WAF4222T5E | LCSC | C23167
MAX4239AUT+T | U1 | MF06A_N | 1 | Maxim Integrated | MAX4239AUT+T | utsource
TI-ADS1015_1115-10 | U2, U4 | PCB-gqbslbs1r8rxldsn6t09-1 | 2 | Texas Instruments | ADS1115IDGST | utsource
ISO154x | U3 | SOIC127P600X265-8N | 1 | Texas Instruments | ISO1541DR | LCSC | C143028
LM4040-2.5 | U5 | MF03A_N | 1 | Diodes Incorporated | LM4040D25FTA | LCSC | C107244
TLV2172IDR | U6 | SOIC-OA8_M | 1 | Texas Instruments | TLV2172IDR | LCSC | C129149
LM358DT | U7 | SOIC-OA8_M | 1 | STMicroelectronics | LM358DT | LCSC | C9418
LM337L | U8 | Z03A | 1 | Texas Instruments | LM337LZ/NOPB | LCSC | C33082
Diodes Inc. AP2204K-5.0TRG1 | U9 | PCB-iw3p7s72x6qbi5zew47f-1 | 1 | Diodes Incorporated | AP2204K-ADJTRG1 | LCSC | C264072
Diodes AZ1117CH-3.3TRG1 | U10, U13 | PCB-15095235-1 | 2 | Diodes Incorporated | AZ1117CH-3.3TRG1 | LCSC | C92102
LMV321SN3T1G | U11 | ONSC-TSOP-5-483-02_V | 1 | Gainsil | LMV321-TR | LCSC | C362273
ULN2803A (SOIC-18) | U12 | PCB-gcdku7p92m9mz9ih2yin-1 | 1 | Mixic | ULN2803A | LCSC | C107219

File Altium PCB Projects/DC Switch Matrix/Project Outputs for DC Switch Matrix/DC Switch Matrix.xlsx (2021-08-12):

Comment | Designator | Footprint | Quantity | Manufacturer | Manufacture Part Number | Supplier | Supplier Part Number
100nF | C1_P1, C1_P2, C1_P3, C1_P4, C1_P5, C1_P6, C1_P7, C1_P8, C2, C3, C9, C11, C13 | CAPC1608X09N, C0603 | 13 | YAGEO | CC0603KRX7R9BB104 | LCSC | C14663
150pF | C4 | C0805 | 1 | YAGEO | CC0805JRNPO9BN151 | LCSC | C107111
10uF | C5, C6, C7, C10, C12, C14 | C0805 | 6 | SAMSUNG | CL21B106KOQNNNE | LCSC | C95841
22uF | C8 | C0603 | 1 | SAMSUNG | CL10A226MP8NUNE | LCSC | C86295
MBR0530T1G | D1 | SOD-123_L2.8-W1.8-LS3.7-RD | 1 | ON | MBR0530T1G | LCSC | C82046
Green | D2, D3, D4 | LED 0603_1608 GREEN | 3 | Orient | ORH-G36G | LCSC | C205443
SN74HC595D | DD1_P1, DD1_P2, DD1_P3, DD1_P4, DD1_P5, DD1_P6, DD1_P7, DD1_P8, DD2, DD3 | PCB-72k1vk0k27b6qyyenbg0-1 | 10 | Nexperia | 74HC595D,118 | LCSC | C5947
DB126V-5.0-2P-GN | J1, J2, J3, J4, J5 | PCB-kiok1jlp9o9fcwf1wwvf-1 | 5 | DIBO | DB126V-5.0-2P-GN | LCSC | C395849
JST S6B-XH-A | J6 | JST S6B-XH-A | 1 | JST Sales America | S6B-XH-A(LF)(SN) | LCSC | C157919
CN-1P-M-R3 | J7 | JST-S3B-XH-A(LF)(SN)_V | 1 | JST Sales America | S3B-XH-A(LF)(SN) | LCSC | C157928
JST B4PS-VH(LF)(SN) | J8, J9 | PCB-fv0n1qe7e7tw0owzte2c-1 | 2 | JST Sales America | B8PS-VH(LF)(SN) | LCSC | C157970
5A Relay | K1_P1, K1_P2, K1_P3, K1_P4, K1_P5, K1_P6, K1_P7, K1_P8, K4_P1, K4_P2, K4_P3, K4_P4, K4_P5, K4_P6, K4_P7, K4_P8, K5_P1, K5_P2, K5_P3, K5_P4, K5_P5, K5_P6, K5_P7, K5_P8, K6_P1, K6_P2, K6_P3, K6_P4, K6_P5, K6_P6, K6_P7, K6_P8 | PCB-ei6nokn2irsc2a7yt94x-1 | 32 | HF(Xiamen Hongfa Electroacoustic) | HF46F/12-HS1 | LCSC | C3636
3A Relay | K2_P1, K2_P2, K2_P3, K2_P4, K2_P5, K2_P6, K2_P7, K2_P8, K3_P1, K3_P2, K3_P3, K3_P4, K3_P5, K3_P6, K3_P7, K3_P8, K7_P1, K7_P2, K7_P3, K7_P4, K7_P5, K7_P6, K7_P7, K7_P8 | PCB-ei6nokn2irsc2a7yt94x-1 | 24 | Omron Electronics | G5NB-1A-E-DC12 | LCSC | C225714
10uH | L1 | IND-SMD_L6.0-W6.0 | 1 | TDK | VLS6045EX-100M | LCSC | C360734
MMBT3906LT1G | Q1_P1, Q1_P2, Q1_P3, Q1_P4, Q1_P5, Q1_P6, Q1_P7, Q1_P8 | SOT-23 | 8 | ON Semiconductor | MMBT3906LT1G | LCSC | C53444
NTMFS4C022NT1G | Q2_P1, Q2_P2, Q2_P3, Q2_P4, Q2_P5, Q2_P6, Q2_P7, Q2_P8 | PCB-iok221h7g3hg093tnixb-1 | 8 | ON Semiconductor | NTMFS4C022NT1G | LCSC | C179623
47k | R1_P1, R1_P2, R1_P3, R1_P4, R1_P5, R1_P6, R1_P7, R1_P8 | gen0603-2 | 8 | UNI-ROYAL(Uniroyal Elec) | 0603WAF4702T5E | LCSC | C25819
4.7k | R2_P1, R2_P2, R2_P3, R2_P4, R2_P5, R2_P6, R2_P7, R2_P8, R3_P1, R3_P2, R3_P3, R3_P4, R3_P5, R3_P6, R3_P7, R3_P8 | gen0603-2 | 16 | YAGEO | RC0603FR-074K7L | LCSC | C99782
205K | R4 | R0603 | 1 | UniOhm | 0603WAF2053T5E | LCSC | C22949
1M | R5 | R0603 | 1 | UniOhm | 0603WAF1004T5E | LCSC | C22935
13.3K | R6 | R0603 | 1 | UniOhm | 0603WAF1332T5E | LCSC | C25952
1k | R7, R8, R9 | gen0603-2 | 3 | YAGEO | RC0603FR-071KL | LCSC | C22548
10k | R10, R11, R12, R13, R14, R15, R16, R17, R18, R19, R20, R21 | gen0603-2 | 12 | YAGEO | RC0603FR-0710KL | LCSC | C98220
ULN2803A (SOIC-18) | U1_P1, U1_P2, U1_P3, U1_P4, U1_P5, U1_P6, U1_P7, U1_P8 | PCB-gcdku7p92m9mz9ih2yin-1 | 8 | Mixic | ULN2803A | LCSC | C107219
Texas Instruments CD4051BNSR | U2, U3, U4 | PCB-xp4qbii5l2bbflfsgoli-1 | 3 | Texas Instruments | CD4051BNSR | LCSC | C87646
LMR62014XMF | U5 | SOT-23-5_L3.0-W1.7-P0.95-LS2.8-BR | 1 | TI | LMR62014XMF | LCSC | C55182
ULN2003ADR | U6, U7 | SOIC-16_L9.9-W3.9-P1.27-LS6.0-BL | 2 | TI | ULN2003ADR | LCSC | C7512
AZ1117CH-3.3TRG1 | U8 | SOT-223-3_L6.5-W3.4-P2.30-LS7.0-BR | 1 | DIODES | AZ1117CH-3.3TRG1 | LCSC | C92102

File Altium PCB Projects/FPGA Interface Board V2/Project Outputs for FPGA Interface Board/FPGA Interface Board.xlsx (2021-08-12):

Comment | Designator | Footprint | Quantity | Manufacturer | Manufacture Part Number | Supplier | Supplier Part Number
100nF | C1, C2, C3, C4, C5, C6, C7, C8, C9, C10, C11, C12, C13, C14, C15, C16, C17, C18, C19, C20, C21, C22, C23, C24, C25, C26, C27, C28, C29, C30, C31, C32, C35, C37, C41, C43, C44 | C0603 | 37 | YAGEO | CC0603KRX7R9BB104 | LCSC | C14663
10uF | C33, C34 | C0805 | 2 | SAMSUNG | CL21B106KOQNNNE | LCSC | C95841
5pF | C36 | C0603 | 1 | Samsung Electro-Mechanics | CL10C050CB8NNNC | LCSC | C93045
22uF | C38, C39 | C0603 | 2 | SAMSUNG | CL10A226MP8NUNE | LCSC | C86295
470nF | C40 | C0603 | 1 | Samsung Electro-Mechanics | CL10F474ZO8NNNC | LCSC | C318652
470nF | C42 | C0603 | 1 | WTC | 0603B474K100 | LCSC | C123513
4.7uF | C45, C46 | CAPC1608X09N | 2 | Samsung Electro-Mechanics | CL10A475KP8NNNC | LCSC | C1705
B8B-XH-A (LF)(SN) | CN1, CN2, CN3 | CONN-TH_B8B-XH-A (LF)(SN) | 3 | JST Sales America | B8B-XH-A (LF)(SN) | LCSC | C157972
B6B-XH-A(LF)(SN) | CN4 | CONN-TH_6P-P2.50_B6B-XH-A(LF)(SN) | 1 | JST Sales America | B6B-XH-A(LF)(SN) | LCSC | C144397
pitch4.2MMsocket2*2P | CN5 | CONN-TH_HAA420A-4A | 1 | BOOMELE | pitch4.2MMsocket2*2P | LCSC | C24697
G | IO_1, IO_2, IO_3, IO_4, IO_5, IO_6, IO_7, IO_8, IO_9, IO_10, IO_11, IO_12, IO_13, IO_14, IO_15, IO_16 | LED0603-R-RD | 16 | Orient | ORH-G36G | LCSC | C205443
Jumper Pad | JP1, JP2 | PCB-sjva3kmaxrqfkswkvsp7-1 | 2
3.3uH | L1 | IND-SMD_L11.5-W10.0_SMMS1040 | 1 | SXN | SMMS1040-3R3M | LCSC | C149592
Header-Female-2.54_1x16 | P1 | HDR-TH_16P-P2.54-V | 1 | BOOMELE | Female header1*16P pitch 2.54mm | LCSC | C66987
51 | R1, R2, R3, R7, R8, R9, R19, R20, R21, R25, R26, R27, R37, R38, R41, R42 | R0603 | 16 | UniOhm | 0603WAF510JT5E | LCSC | C23197
100 | R4, R5 | gen0603-2 | 2 | UNI-ROYAL(Uniroyal Elec) | 0603WAF1000T5E | LCSC | C22775
10K | R6, R22, R49, R53 | R0603 | 4 | YAGEO | RC0603FR-0710KL | LCSC | C98220
100K | R10 | R0603 | 1 | UniOhm | 0603WAF1003T5E | LCSC | C25803
49.9K | R11 | R0603 | 1 | UniOhm | 0603WAF4992T5E | LCSC | C23184
1K | R12, R13, R14, R15, R16, R17, R18, R31, R32, R33, R34, R35, R36, R45, R46, R47, R48, R54, R55, R56, R57, R58, R59, R60, R61, R62, R63, R64, R65, R66, R67, R68, R69 | R0603 | 33 | YAGEO | RC0603FR-071KL | LCSC | C22548
51k | R50 | PCB-3elf45qdqizoabmczrxc-1 | 1 | Walsin Tech Group | WR06X513 JTL | LCSC | C384211
24k | R51 | PCB-3elf45qdqizoabmczrxc-1 | 1 | UNI-ROYAL(Uniroyal Elec) | 0603WAJ0243T5E | LCSC | C25588
105K | R52 | R0603 | 1 | UniOhm | 0603WAF1053T5E | LCSC | C16840
KH-SMA-K513-G | RF1, RF2 | ANT-TH_KH-SMA-K513-G | 2 | Shenzhen Kinghelm Elec | KH-SMA-K513-G | LCSC | C411575
G5NB-1A-E-DC12 | RLY1, RLY2, RLY3, RLY4, RLY5, RLY6, RLY7, RLY8, RLY9, RLY10, RLY11, RLY12, RLY13, RLY14, RLY15, RLY16 | RELAY-TH_G5NB-1A-E-DCXX | 16 | Omron Electronics | G5NB-1A-E-DC12 | LCSC | C225714
MCP1826T-ADJE/DC | U1 | MCP1826T-ADJE/DC | 1 | Microchip Tech | MCP1826T-ADJE/DC | LCSC | C147898
DE0 NANO UPSIDE-DOWN PIN HEADERS COPY | U2 | DE0-NANO UPSIDE DOWN | 1
74LVCH2T45DC-Q100H | U3, U4, U5, U6, U7, U8, U9, U10, U11, U12, U13, U14, U15, U16, U17, U18 | VSSOP-8_L2.4-W2.1-P0.50-LS3.2-BR | 16 | Nexperia | 74LVCH2T45DC-Q100H | LCSC | C116382
TPS56528DDAR | U19 | SOIC-8_L4.9-W3.9-P1.27-LS6.0-BL-EP | 1 | Texas Instruments | TPS56528DDAR | LCSC | C138716
L78M06CDT-TR | U20 | VREG_L78M06CDT-TR | 1 | STMicroelectronics | L78M06CDT-TR | LCSC | C157444
ULN2803A_C107219 | U21, U23 | SOP-18_L11.4-W7.6-P1.27-LS10.6-BL | 2 | MIXIC | ULN2803A | LCSC | C107219
74HC595D,118 | U22, U24 | SOIC-16_L9.9-W3.9-P1.27-LS6.0-BL | 2 | Nexperia | 74HC595D,118 | LCSC | C5947

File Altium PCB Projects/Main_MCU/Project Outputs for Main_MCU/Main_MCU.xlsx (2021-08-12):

Comment | Designator | Footprint | Quantity | Manufacturer | Manufacture Part Number | Supplier | Supplier Part Number
HNB09A03 | BUZZER1 | BUZ-TH_BD9.0-P5.00-D0.6-FD | 1 | Jiangsu Huaneng Elec | HNB09A03 | LCSC | C96102
1uF | C1, C2, C3, C4, C8, C12, C13 | C0805 | 7 | SAMSUNG | CL10A105KP8NNNC | LCSC | C26413
100nF | C5, C6, C7, C9, C11, C14 | C0603 | 6 | YAGEO | CC0603KRX7R9BB104 | LCSC | C14663
10uF | C10 | C0805 | 1 | SAMSUNG | CL21B106KOQNNNE | LCSC | C95841
470nF | C15 | C0603 | 1 | WTC | 0603B474K100 | LCSC | C123513
pitch4.2MMsocket2*2P | CN1 | CONN-TH_HAA420A-4A | 1 | BOOMELE | pitch4.2MMsocket2*2P | LCSC | C24697
USB-B-Female-TH_C46393 | CN2, CN3 | USB-B_TH_BF90 | 2 | Jing Extension of the Electronic Co. | C46393 | LCSC | C46393
B8B-XH-A (LF)(SN) | CN5, CN6, CN7, CN8, CN9, CN10, CN13, CN14, CN15, CN18, CN19, CN20 | CONN-TH_B8B-XH-A (LF)(SN) | 12 | JST Sales America | B8B-XH-A (LF)(SN) | LCSC | C157972
B6B-XH-A(LF)(SN) | CN11, CN12, CN16, CN17, U3, U4 | CONN-TH_6P-P2.50_B6B-XH-A(LF)(SN) | 6 | JST Sales America | B6B-XH-A(LF)(SN) | LCSC | C144397
CUS08F30,H3F | D1 | SOD-323F_L2.0-W1.6-LS2.5-RD | 1 | TOSHIBA | CUS08F30,H3F | LCSC | C150183
A2541WV-2P | H1, H2, H3, H4 | HDR-TH_P2.54-H-M_A2541WV-2P | 4 | CJT(Changjiang Connectors) | A2541WV-2P | LCSC | C225477
GREEN | LED1, LED2, LED3, LED4 | LED0603-R-RD | 4 | Orient | ORH-G36G | LCSC | C205443
RED | LED5, LED6 | LED0603-R-RD | 2 | EVERLIGHT | 19-217/R6C-AL1M2VY/3T | LCSC | C72044
ORANGE | LED7, LED8 | LED0603-R-RD | 2 | Orient | ORH-R36A(0.6T) | LCSC | C205445
MMBT3904LT1G | Q1 | SOT-23-3_L2.9-W1.6-P1.90-LS2.8-BR | 1 | ON | MMBT3904LT1G | LCSC | C81464
10K | R1, R2, R3, R4, R5, R6, R7, R8, R11, R19, R32 | R0603 | 11 | YAGEO | RC0603FR-0710KL | LCSC | C98220
4.7K | R9, R10, R13, R14 | R0603 | 4 | YAGEO | RC0603FR-074K7L | LCSC | C99782
100 | R12 | R0603 | 1 | UniOhm | 0603WAF1000T5E | LCSC | C22775
1K | R15, R24, R25, R26, R27, R28, R29, R30, R31 | R0603 | 9 | YAGEO | RC0603FR-071KL | LCSC | C22548
22 | R16, R17 | R0603 | 2 | UniOhm | 0603WAJ0220T5E | LCSC | C1203
10 | R18, R20, R22, R23 | R0603 | 4 | YAGEO | RC0603FR-0710RL | LCSC | C109318
5.1 | R21 | R0603 | 1 | UniOhm | 0603WAF510KT5E | LCSC | C25197
SMA 50Ohm Coaxial Connectors | RF1, RF2, RF3, RF4 | BWSMA-KE-Z001 | 4 | BAT WIRELESS | BWSMA-KE-Z001 | LCSC | C496549
DB126V-5.0-2P | U1, U2 | CONN-TH_2P-P5.00_L7.8-W10.0 | 2 | DIBO | DB126V-5.0-2P | LCSC | C395849
MCP2551-I/SN | U5 | SOIC-8_L4.9-W3.9-P1.27-LS6.0-BL | 1 | MICROCHIP | MCP2551-I/SN | LCSC | C7376
STM32F103ZET Mini Dev Board | U6 | STM32F103ZET MINI DEV BOARD | 1
B4B-XH-A(LF)(SN) | U7, U11 | CONN-TH_B4B-XH-A (LF)(SN) | 2 | JST Sales America | B4B-XH-A(LF)(SN) | LCSC | C144395
SI5351A-B-GT | U8 | MSOP-10_L3.0-W3.0-P0.50-LS5.0-BL | 1 | SILICON LABS | SI5351A-B-GT | LCSC | C529366
MCP4728-E/UN | U9 | MSOP-10_L3.0-W3.0-P0.50-LS5.0-TL | 1 | Microchip Tech | MCP4728-E/UN | LCSC | C108207
CDCLVC1104PWR | U10 | TSSOP-8_L4.4-W3.0-P0.65-LS6.4-BL | 1 | Texas Instruments | CDCLVC1104PWR | LCSC | C485518
MCP2221A-I/ST | U12 | TSSOP-14_L5.0-W4.4-P0.65-LS6.4-BL | 1 | MICROCHIP | MCP2221A-I/ST | LCSC | C130462
27MHz | X1 | OSC-SMD_4P-L2.5-W2.0-BL | 1 | Seiko Epson | Q24FA20H00238 | LCSC | C255960

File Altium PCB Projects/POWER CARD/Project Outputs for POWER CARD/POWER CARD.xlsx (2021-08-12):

Comment | Designator | Footprint | Quantity | Manufacturer | Manufacture Part Number | Supplier | Supplier Part Number
22uF | C1 | PCB-jngp9cavmssoy37xiwaz-1 | 1 | Lelon | OCV220M1VTR-0606 | LCSC | C473426
10uF | C2, C30, C31, C33_L1, C33_L2, C33_L3, C35, C39 | CAPC3216X127X50ML20T25 | 8 | Samsung Electro-Mechanics | CL31B106KBHNNNE | LCSC | C89632
100nF | C3, C10, C11, C12, C13, C16, C17, C20, C27, C32_L1, C32_L2, C32_L3, C36, C38, C42, C43, C44, C45 | CAPC1608X09N | 18 | YAGEO | CC0603KRX7R9BB104 | LCSC | C14663
1uF | C4, C5, C40 | CAPC1608X09N | 3 | Samsung Electro-Mechanics | CL21B105KBFNNNE | LCSC | C28323
1.5nF | C6 | CAPC1608X09N | 1 | Walsin Tech Corp | 0603B152K500CT | LCSC | C302015
22nF | C7 | CAPC1608X09N | 1 | Samsung Electro-Mechanics | CL10B223KB8NNNC | LCSC | C21122
47nF | C8 | CAPC1608X09N | 1 | Walsin Tech Corp | 0603F473M500CT | LCSC | C387994
4.7uF | C9, C41 | CAPC1608X09N | 2 | Samsung Electro-Mechanics | CL10A475KP8NNNC | LCSC | C1705
20pF | C14, C15 | CAPC1608X09N | 2 | YAGEO | CC0603JRNPO9BN200 | LCSC | C105621
22uF | C18, C24, C25 | CAPC1608X09N | 3 | Samsung Electro-Mechanics | CL10A226MP8NUNE | LCSC | C86295
10uF | C19, C22, C23 | C0805 | 3 | Samsung Electro-Mechanics | CL21B106KOQNNNE | LCSC | C95841
5pF | C21 | CAPC1608X09N | 1 | Samsung Electro-Mechanics | CL10C050CB8NNNC | LCSC | C93045
470nF | C26 | CAPC1608X09N | 1 | Samsung Electro-Mechanics | CL10F474ZO8NNNC | LCSC | C318652
100uF | C28 | PCB-qvt8zv9h5ffid452gs9x-1 | 1 | Rubycon | 50YXF100MFFC8X11.5 | LCSC | C324036
150pF | C29 | C0805 | 1 | YAGEO | CC0805JRNPO9BN151 | LCSC | C107111
100pF | C34_L1, C34_L2, C34_L3 | CAPC1608X09N | 3 | Walsin Tech Corp | 0603N101J500CT | LCSC | C335544
10nF | C37 | CAPC1608X09N | 1 | Samsung Electro-Mechanics | CL10B103KC8NNNC | LCSC | C84709
 | D1 | PCB-z3532lqu4iri8rzc55ux-1 | 1 | Diodes Incorporated | B540C-13-F | LCSC | C72264
Green | D2, D3, D4, D5, D6 | PCBComponent_1 - duplicate | 5 | Orient | ORH-G36G | LCSC | C205443
TPS55340RTER | IC1 | VfQFPN 3x3x1.0 16L | 1 | Texas Instruments | TPS55340RTER | LCSC | C169167
TPS56528DDAR | IC2 | PCB-duyb6heo4lj5grkfxin6-1 | 1 | Texas Instruments | TPS56528DDAR | LCSC | C138716
LM358DT | IC3_L1, IC3_L2, IC3_L3, IC4, IC5 | SOIC-OA8_M | 5 | STMicroelectronics | LM358DT | LCSC | C9418
CMP-a6466f3bff057981-11 | J1 | PCB-z52whxwf67d3eu6gna8s-1 | 1 | JST Sales America | B4B-XH-A (LF)(SN) | LCSC | C144395
TE Connectivity / AMP 3-644456-5, CMP-7ab1b1e1ad8ca576-12, M20-9990346, Jumper Pad, Test Point | J2, J3, J4, J5, J6, J10, J13, J14, J15, JP1, TP1, TP2, TP3, TP4, TP5, TP6 | PCB-rnlen50cc5tt6vc22c1r-1, PCB-oudem42uhcimrbfznktg-1, PIN_3x1_STR (2.54mm), PCB-sjva3kmaxrqfkswkvsp7-1, PCB-76sf9akqozhr8i1vmz2c-1 | 16
DB126V-5.0-2P-GN | J7, J8, J9, J11, J12 | PCB-kiok1jlp9o9fcwf1wwvf-1 | 5 | DIBO | DB126V-5.0-2P-GN | LCSC | C395849
3A Relay | K1, K2, K3 | PCB-ei6nokn2irsc2a7yt94x-1 | 3 | Omron Electronics | G5NB-1A-E-DC12 | LCSC | C225714
10uH 3.6A | L1, L3 | PCB-aqghgth2fl3irtnr7nhi-1 | 2 | TDK | SPM6530T-100M-HZ | LCSC | C360728
3.3uH | L2 | PCB-grsryisdn8451x3s484y-1 | 1 | SXN | SMMS1040-3R3M | LCSC | C149592
MMBT3904LT1G | Q1, Q4_L1, Q4_L2, Q4_L3, Q5_L1, Q5_L2, Q5_L3 | SOT-23 | 7 | ON Semiconductor | MMBT3904LT1G | LCSC | C81464
Part | Q2 | PCB-tryrgihdrozpg2dv6q87-1 | 1 | TOSHIBA | TLP785(GB-TP6,F(C | LCSC | C45445
NPN | Q3_L1, Q3_L2, Q3_L3 | PCB-h3r3bzz71pyabhalkrge-1 | 3 | Texas Instruments | INA138NA/3K | LCSC | C47914
187k | R1 | gen0603-2 | 1 | UNI-ROYAL(Uniroyal Elec) | 0603WAF1873T5E | LCSC | C22896
1k | R2, R5, R14, R15, R17 | gen0603-2 | 5 | YAGEO | RC0603FR-071KL | LCSC | C22548
10k | R3, R6, R13, R19, R20, R27, R29, R34, R37_L1, R37_L2, R37_L3, R39_L1, R39_L2, R39_L3, R46, R47, R48, R49, R50 | gen0603-2 | 19 | YAGEO | RC0603FR-0710KL | LCSC | C98220
51k | R4, R26 | PCB-3elf45qdqizoabmczrxc-1 | 2 | Walsin Tech Group | WR06X513 JTL | LCSC | C384211
1M | R7 | PCB-3elf45qdqizoabmczrxc-1 | 1 | UNI-ROYAL(Uniroyal Elec) | 0603WAF1004T5E | LCSC | C22935
47k | R8, R9, R10, R11 | PCB-3elf45qdqizoabmczrxc-1 | 4 | UNI-ROYAL(Uniroyal Elec) | 0603WAF4702T5E | LCSC | C25819
100 | R12, R36_L1, R36_L2, R36_L3, R44, R45 | gen0603-2 | 6 | UNI-ROYAL(Uniroyal Elec) | 0603WAF1000T5E | LCSC | C22775
0.1 | R16, R21, R22, R23, R24, R25, R31 | RESC3116X07M | 7 | UNI-ROYAL(Uniroyal Elec) | 1206W4F100LT5E | LCSC | C25334
14.3k | R18 | gen0603-2 | 1 | UNI-ROYAL(Uniroyal Elec) | 0603WAF1432T5E | LCSC | C22799
24k | R28 | PCB-3elf45qdqizoabmczrxc-1 | 1 | UNI-ROYAL(Uniroyal Elec) | 0603WAJ0243T5E | LCSC | C25588
105k | R30 | gen0603-2 | 1 | UNI-ROYAL | 0603WAF1053T5E | LCSC | C16840
16.2k | R32 | PCB-3elf45qdqizoabmczrxc-1 | 1 | UNI-ROYAL(Uniroyal Elec) | 0603WAF1622T5E | LCSC | C22885
118k | R33 | PCB-3elf45qdqizoabmczrxc-1 | 1 | UNI-ROYAL(Uniroyal Elec) | 0603WAF1183T5E | LCSC | C25806
4.7k | R35, R40, R41, R42, R43 | gen0603-2 | 5 | YAGEO | RC0603FR-074K7L | LCSC | C99782
100k | R38_L1, R38_L2, R38_L3 | PCB-3elf45qdqizoabmczrxc-1 | 3 | Walsin Tech Corp | WR06X1003FTL | LCSC | C132374
CMP-3c1bf499dccde3dc-3 | S1, S2 | PCB-884bonwl6v4pb9lbnr4u-1 | 2 | Korean Hroparts Elec | K2-1107ST-A4SW-06 | LCSC | C118141
Jiangsu Huaneng Elec HNB09A03 | SP1 | PCB-gql0f0yk39bxcwo1gexj-1 | 1 | Jiangsu Huaneng Elec | HNB09A03 | LCSC | C96102
STM32F103C8T6TR | U1 | STM-LQFP48_M | 1 | STMicroelectronics | STM32F103C8T6 | LCSC | C8734
MCP2551-I/SN | U2 | PCB-j27wim3vo61mdxz6aows-1 | 1 | Microchip Tech | MCP2551-I/SN | LCSC | C7376
Diodes AZ1117CH-3.3TRG1 | U3 | PCB-15095235-1 | 1 | Diodes Incorporated | AZ1117CH-3.3TRG1 | LCSC | C92102
CON-DAC-MCP4728-10 | U4, U6 | PCB-psrfqusngns6snaz1e8o-1 | 2 | Microchip Tech | MCP4728-E/UN | LCSC | C108207
LM4040B50FTA | U5 | PCB-bxhnyzncanvi69437o7v-1 | 1 | Diodes Incorporated | LM4040B50FTA | LCSC | C460606
Mixic ULN2001D | U7 | PCB-pxs93rufbf6wijgtyo7d-1 | 1 | Mixic | ULN2001D | LCSC | C108905
OPA548T | U8 | TI-KVT7 | 1 | Texas Instruments | OPA548T | LCSC | C138712
TPS54202DDCR | U9 | PCB-3e3nvufahczdahdcyxrk-1 | 1 | Texas Instruments | TPS54202DDCR | LCSC | C191884
LM337L | U10 | Z03A | 1 | Texas Instruments | LM337LZ/NOPB | LCSC | C33082
500 | VR1 | PCB-8uuv2uwn1geg2g5qqyha-1 | 1 | BOCHEN(Chengdu Guosheng Tech) | 3296W-1-501 | LCSC | C118913
2k | VR2, VR3 | PCB-5abvnr99iwiiosfurk6j-1 | 2 | BOCHEN(Chengdu Guosheng Tech) | 3296W-1-202 | LCSC | C118206
8MHz | X1 | XTAL1 | 1 | Yangxing Tech | X49SD8MSD2SC | LCSC | C21263

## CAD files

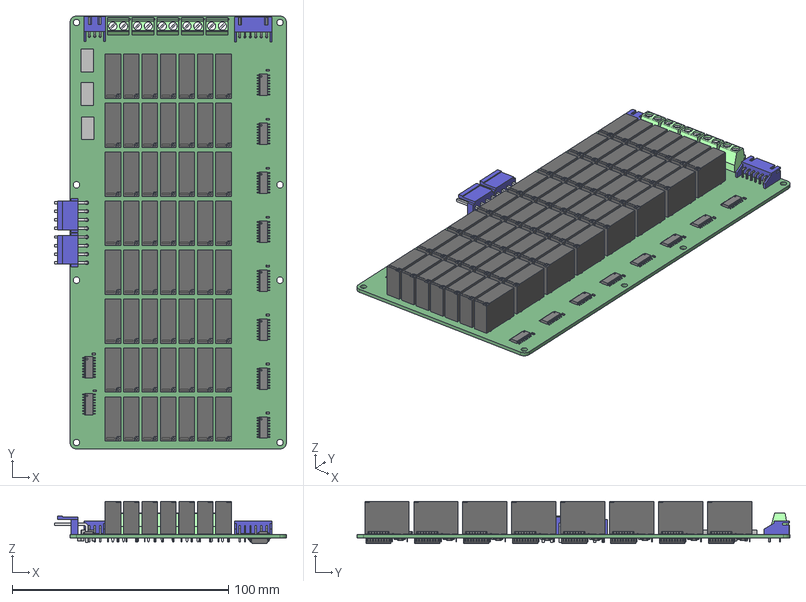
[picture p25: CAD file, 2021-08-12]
Altium PCB Projects/DC Switch Matrix/Switch Matrix PCB.step
107.2 x 200.0 x 19.5 mm
G5NB_1A x 56
Extruded x 6
mkdsn_1.5-2 x 5
B4PS-VH x 2
User_Library-SOIC-18-300_pin_SOIC_SO-300_1 x 144
User_Library-SOIC-18-300_SOIC_300_SOIC_11.75X7.6_1 x 8
User_Library-RES_1609-0603 x 24
User_Library-SOT-23-4 x 8
S3B-XH-A
S6B-XH-A
SOIC_16 x 10
06035c103kat2a x 10

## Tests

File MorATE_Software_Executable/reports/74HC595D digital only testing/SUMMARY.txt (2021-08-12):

##################MorATE TEST REPORT SUMMARY#########################
  Project  : 74HC595D
  Operator : User
  Date     : Mon Jul 26 2021
  Time     : 17:29:49
#####################################################################

  Total ICs tested     : 1
ID of the starting IC  : 1
ID of the last IC      : 1
  No. of ICs passed    : 1
  No. of ICs failed    : 0

  List of failed ICs   : 
##########################################################

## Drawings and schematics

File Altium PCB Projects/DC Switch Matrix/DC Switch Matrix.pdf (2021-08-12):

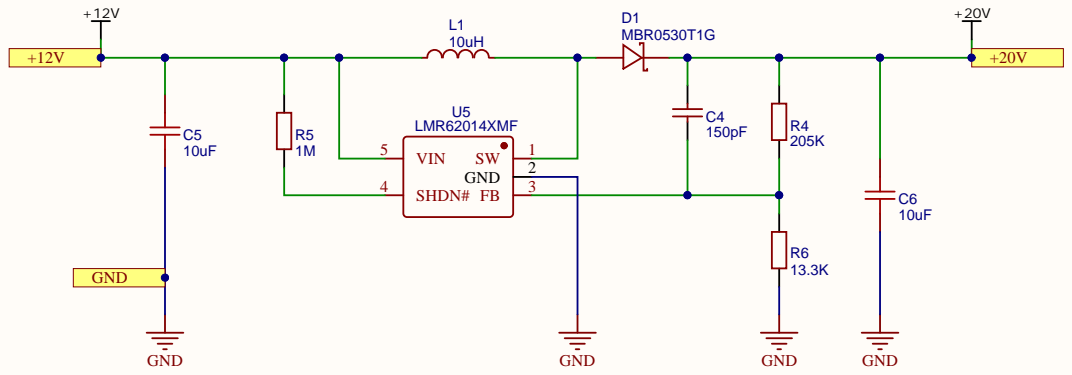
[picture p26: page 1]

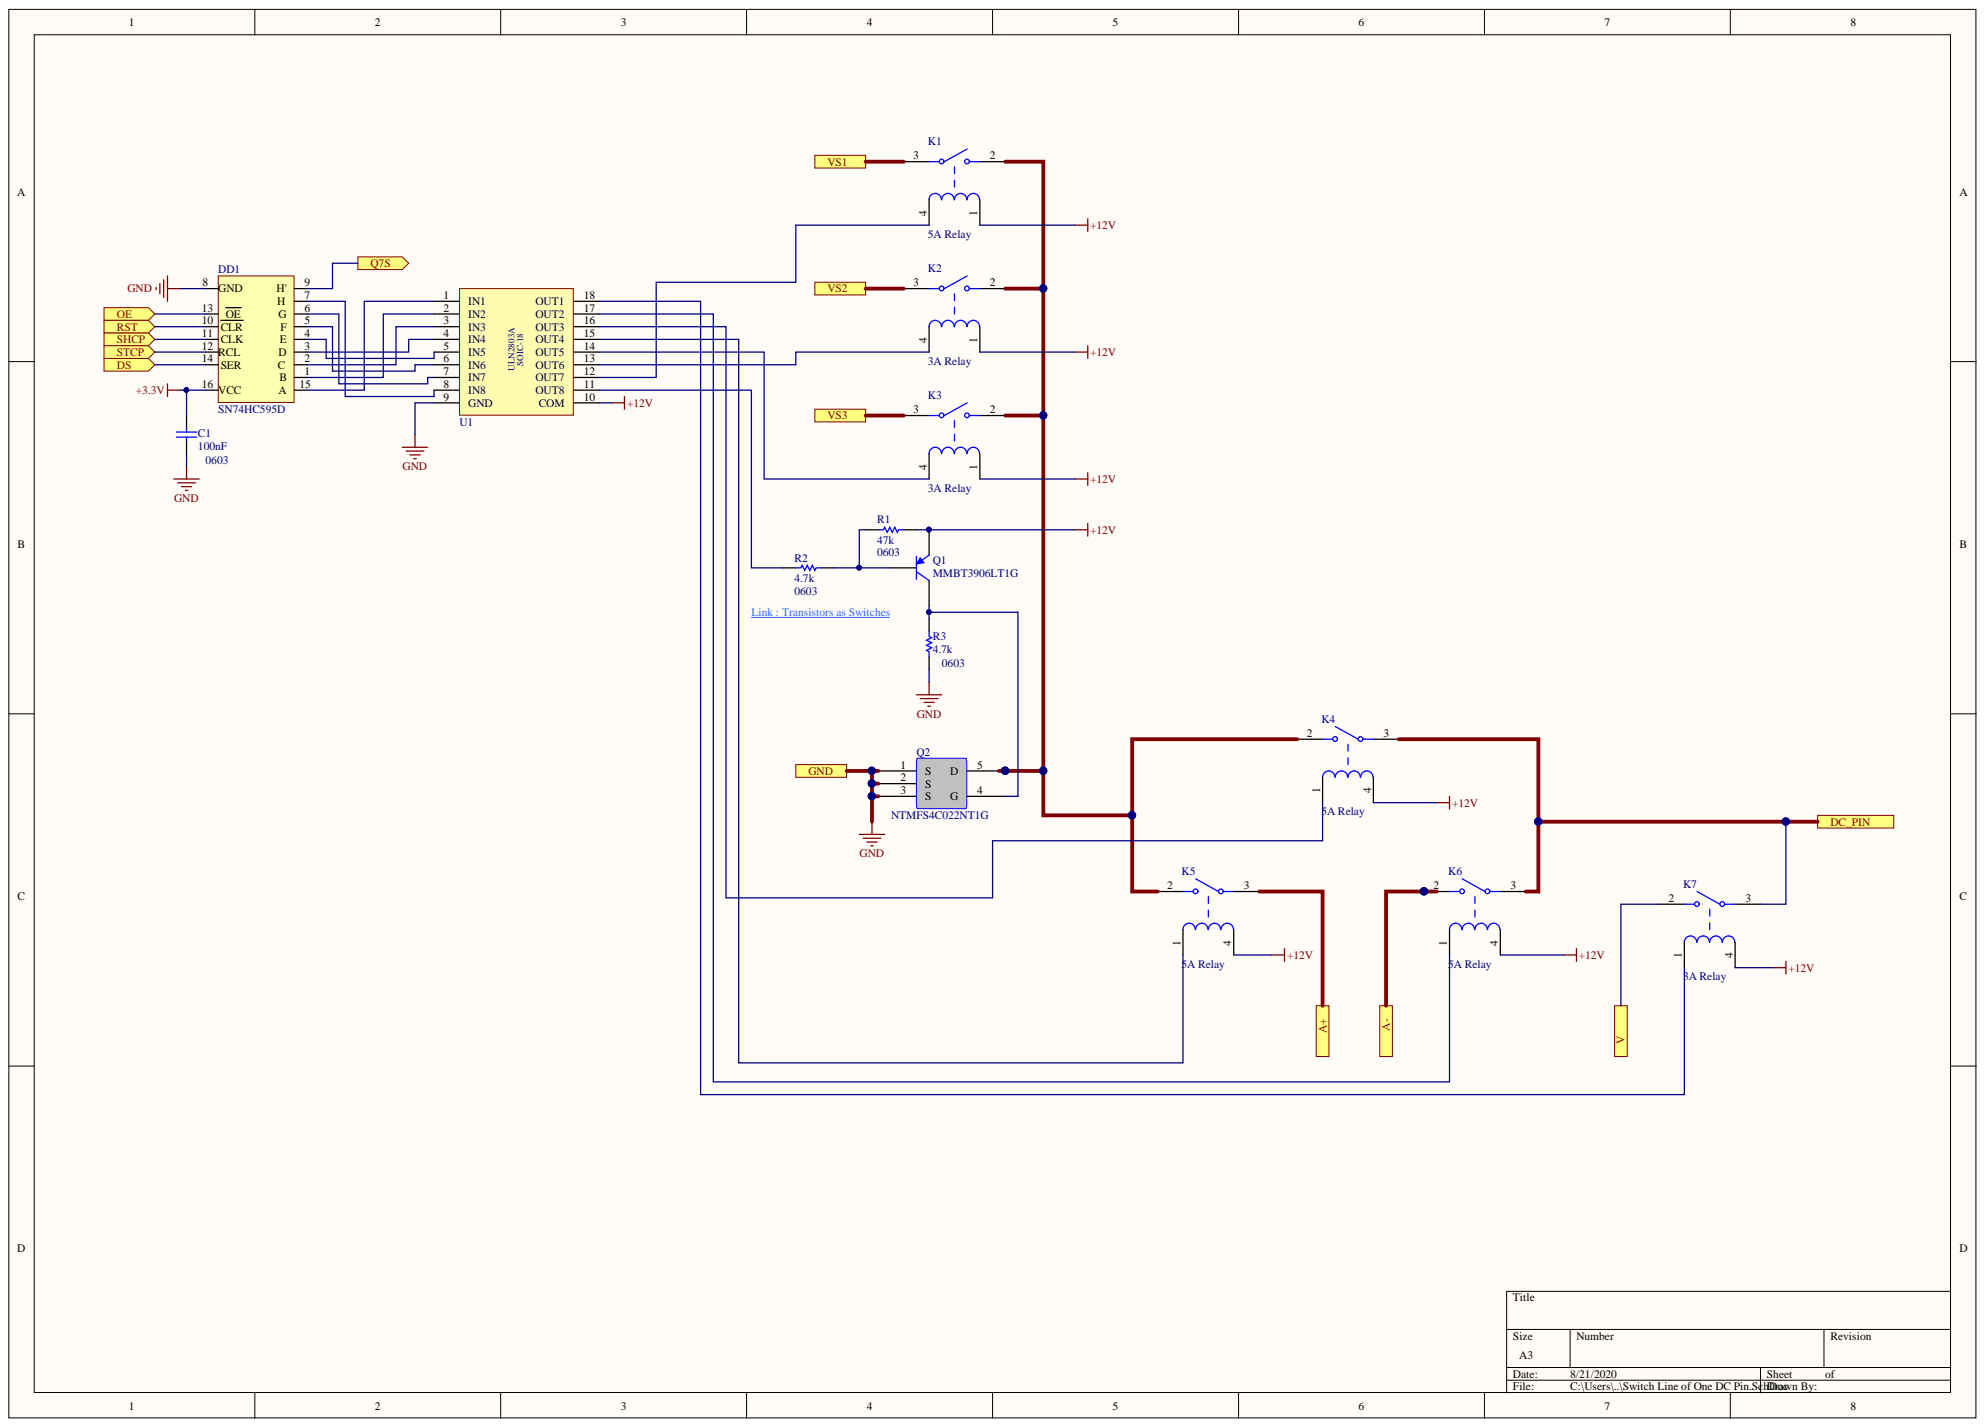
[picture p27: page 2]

RCL 12 SER 14 | IN6 6

Link : Transistors as Switches (https://pe2bz.philpem.me.uk/Power/-%20Pulse/Info-UsingBipolarTransistors-as-Switches/transwit.htm)

GND | S 2

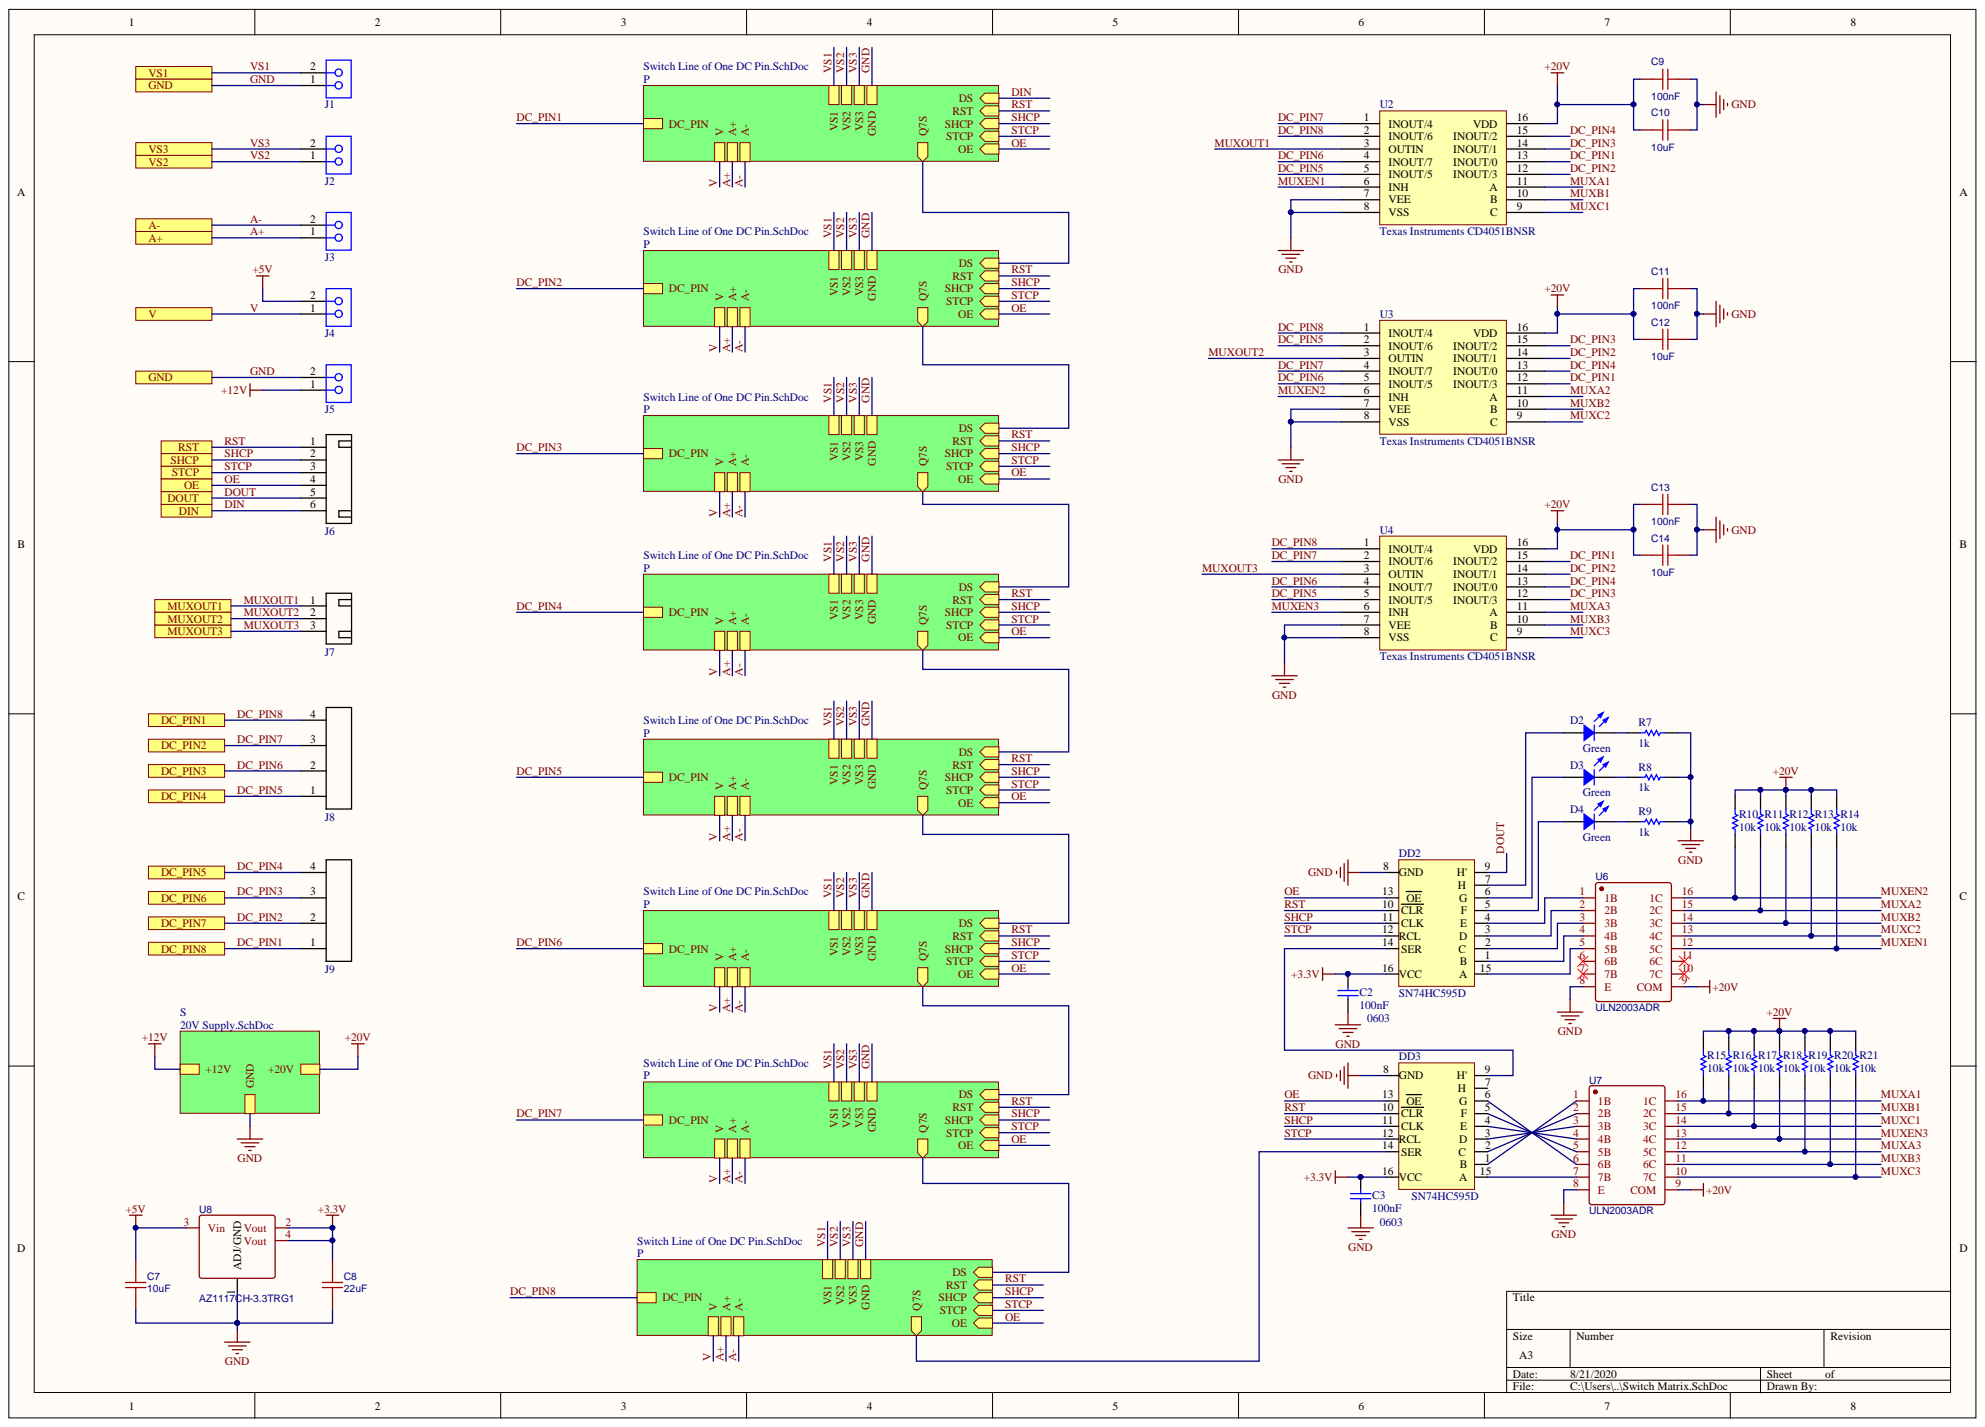
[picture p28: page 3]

RST STCP

RST | SHCP 2
SHCP | STCP 3
STCP | OE 4
OE | DOUT 5
DOUT | 6

MUXOUT2 | MUXOUT2 2
MUXOUT3 | MUXOUT3 3

ADJ/GND 1 Vout 2 Vin 3

Switch Line of One DC Pin.SchDoc

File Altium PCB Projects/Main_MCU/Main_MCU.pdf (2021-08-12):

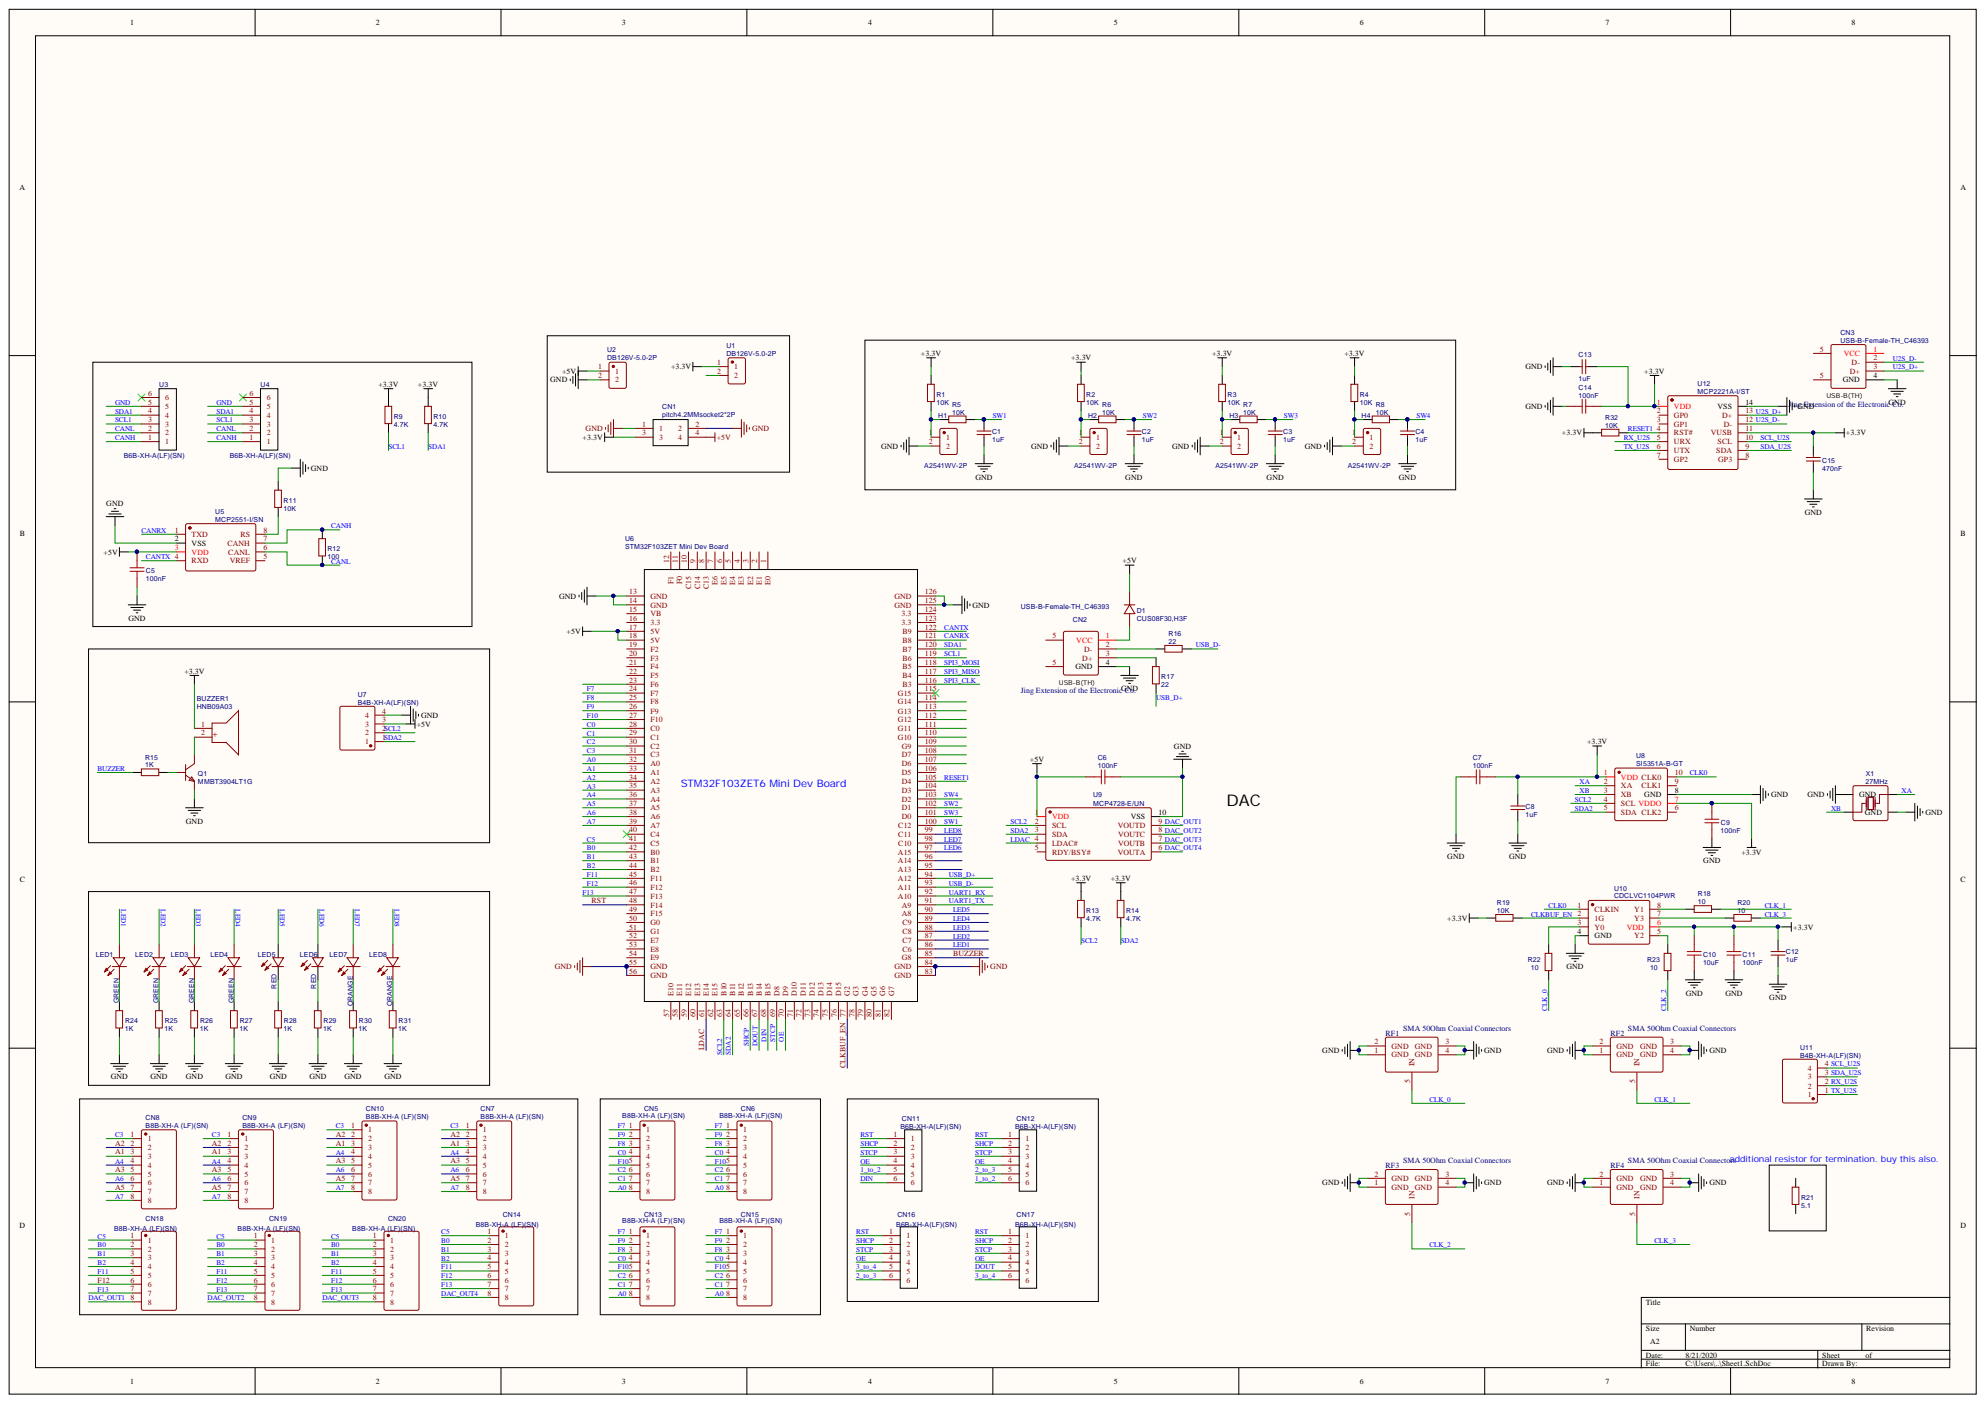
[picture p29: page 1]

Jing Extension of the Ele
GND

G7 82 GND 83 GND 84 G8 85 C6 86 C7 87 C8 88 C9 89 A8 90 A9 91 A10 92 A11 93 A12 94 A13 95 A14 96 A15 97 C10 98 C11 99 C12 100 D0 101 D1 102 D2 103 D3 104 D4 105 D5 106 D6 107 D7 108 G9 109 G10 110 G11 111 G12 112 G13 113 G14 114 G15 115 B3 116 B4 117 B5 118 B6 119 B7 120 B8 121 B9 122 3.3 123 3.3 124 GND 125 GND 126

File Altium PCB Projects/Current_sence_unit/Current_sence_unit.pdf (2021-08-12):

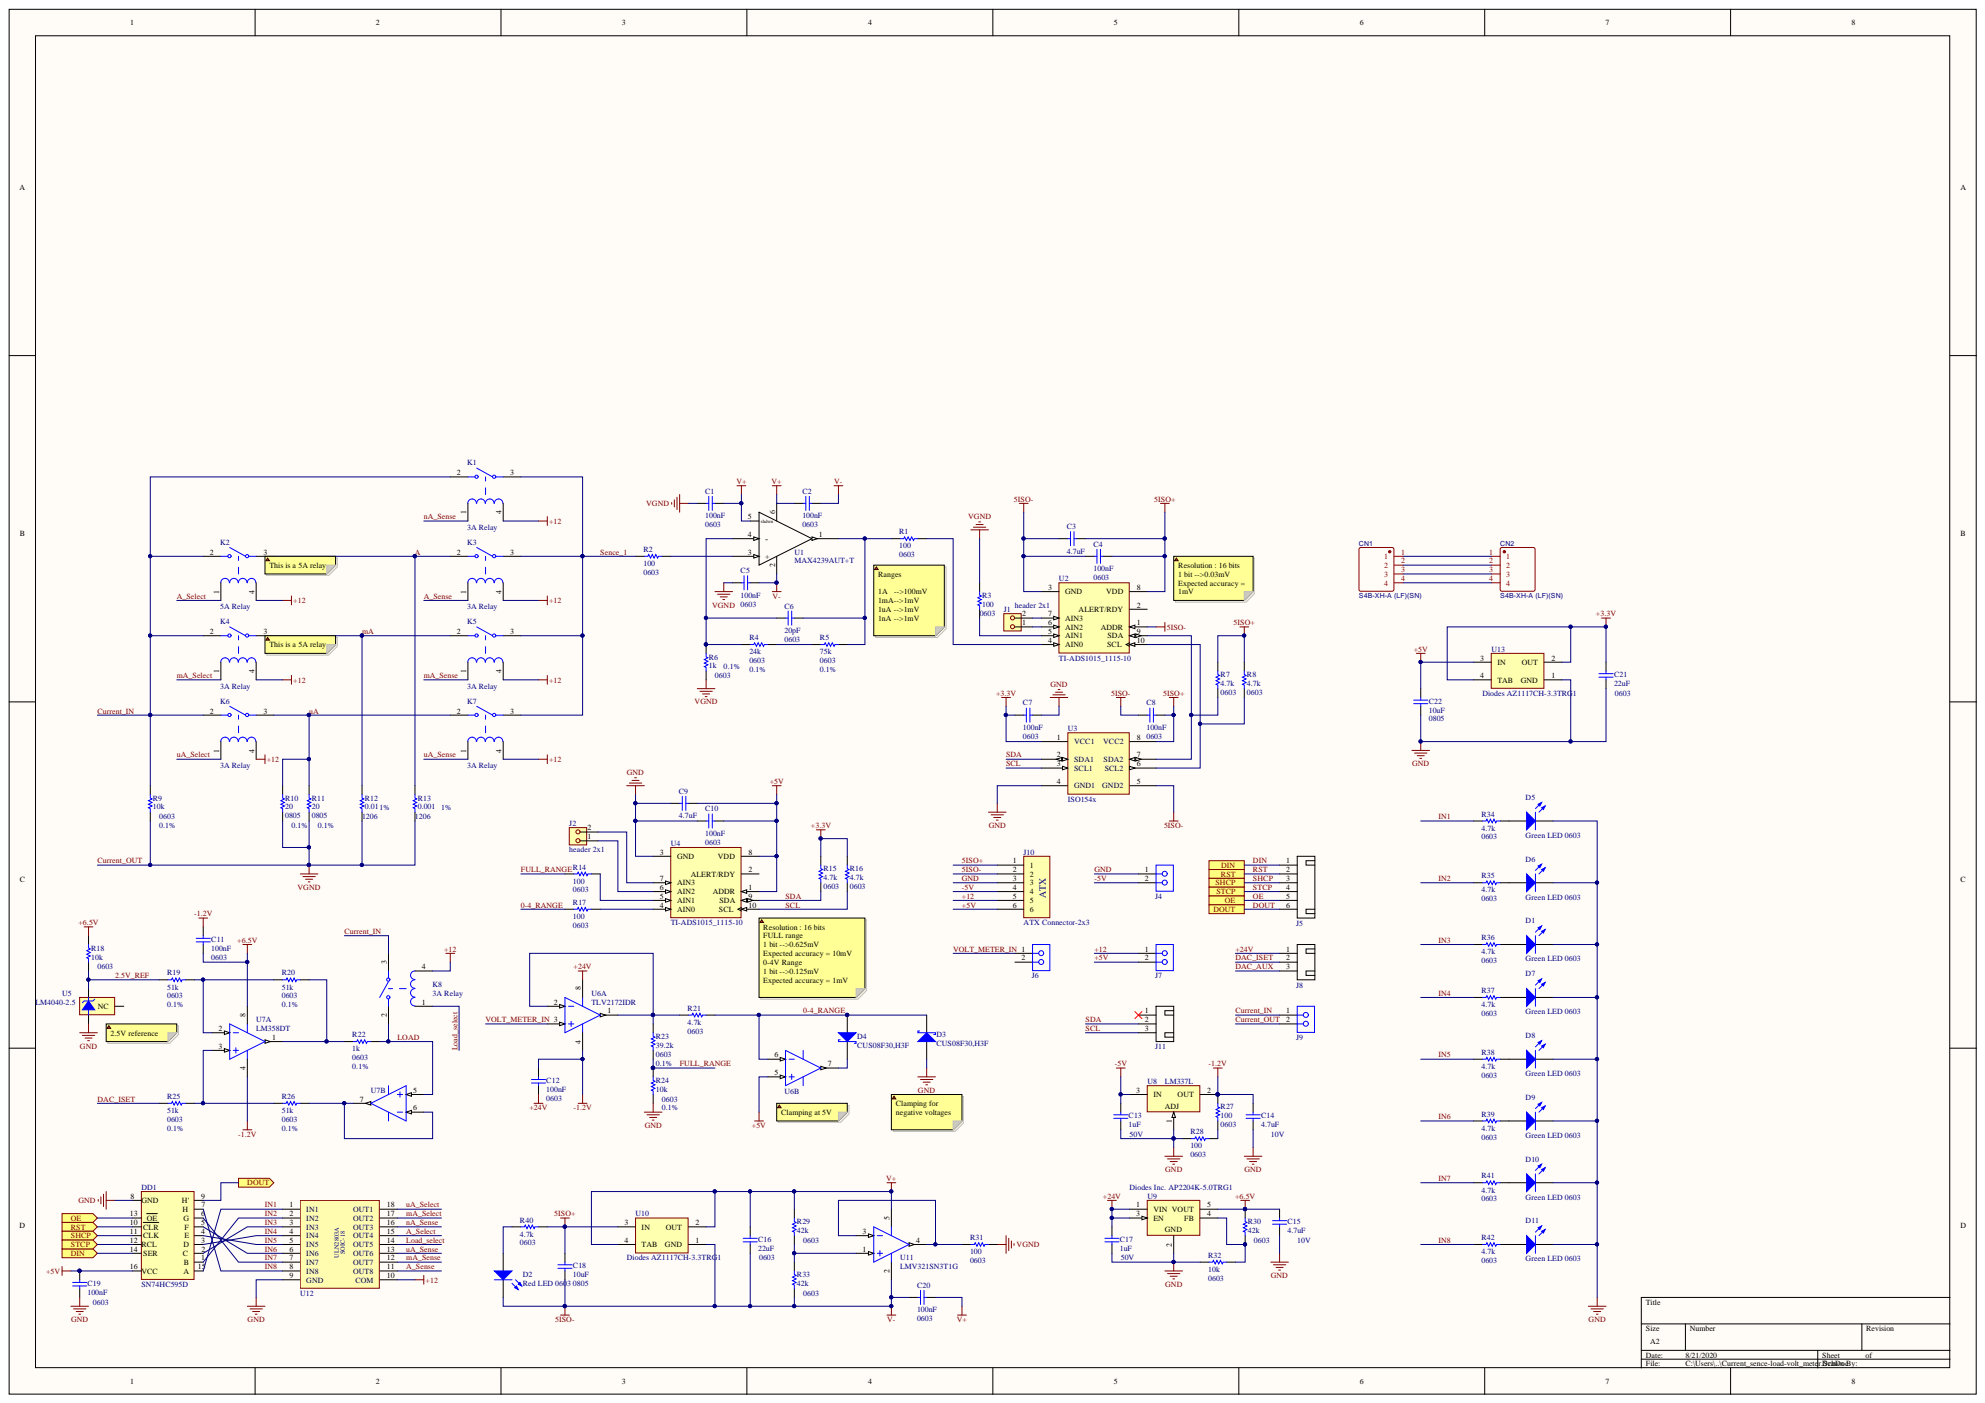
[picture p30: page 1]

1 | AIN0 4 AIN1 5 AIN2 6 AIN3 7

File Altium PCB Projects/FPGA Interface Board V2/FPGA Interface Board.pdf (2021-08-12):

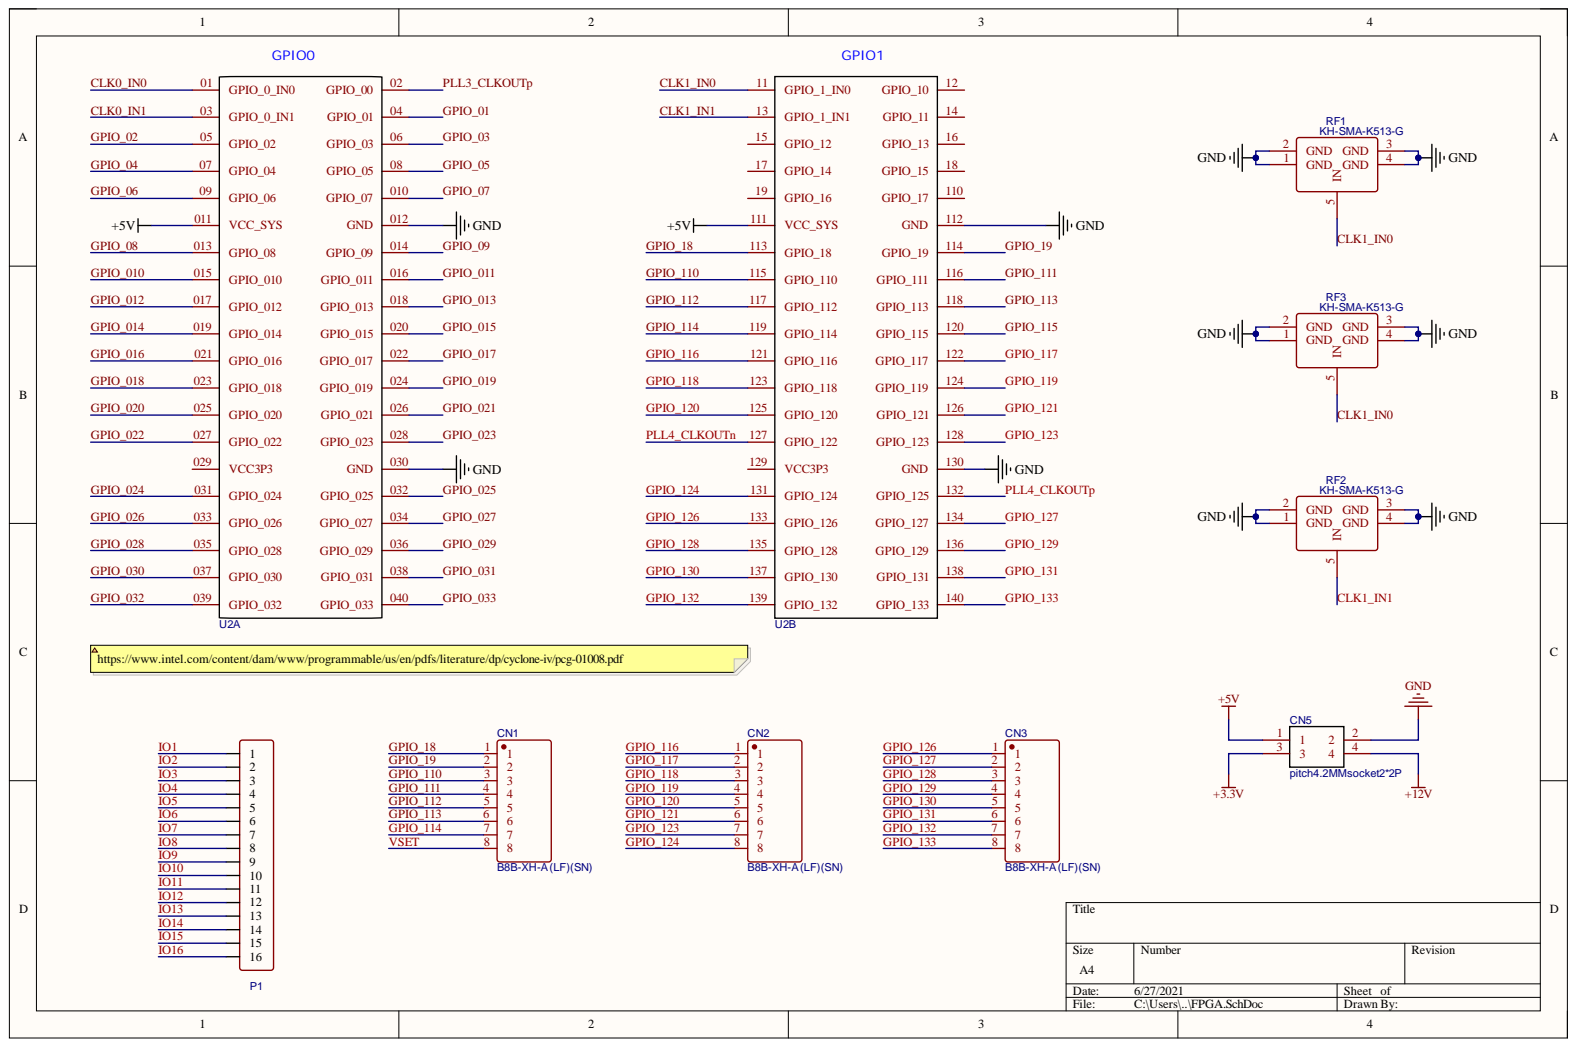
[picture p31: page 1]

com/content/dam/www/progr

ammable/us/en/pdfs/lite

Siz e A4 | Numb e r | R evisio n

Da te : 6/27/202 1 | She et of
File : C:\Use rs\. .\F PGA . S c hD o c | Dr awn By:

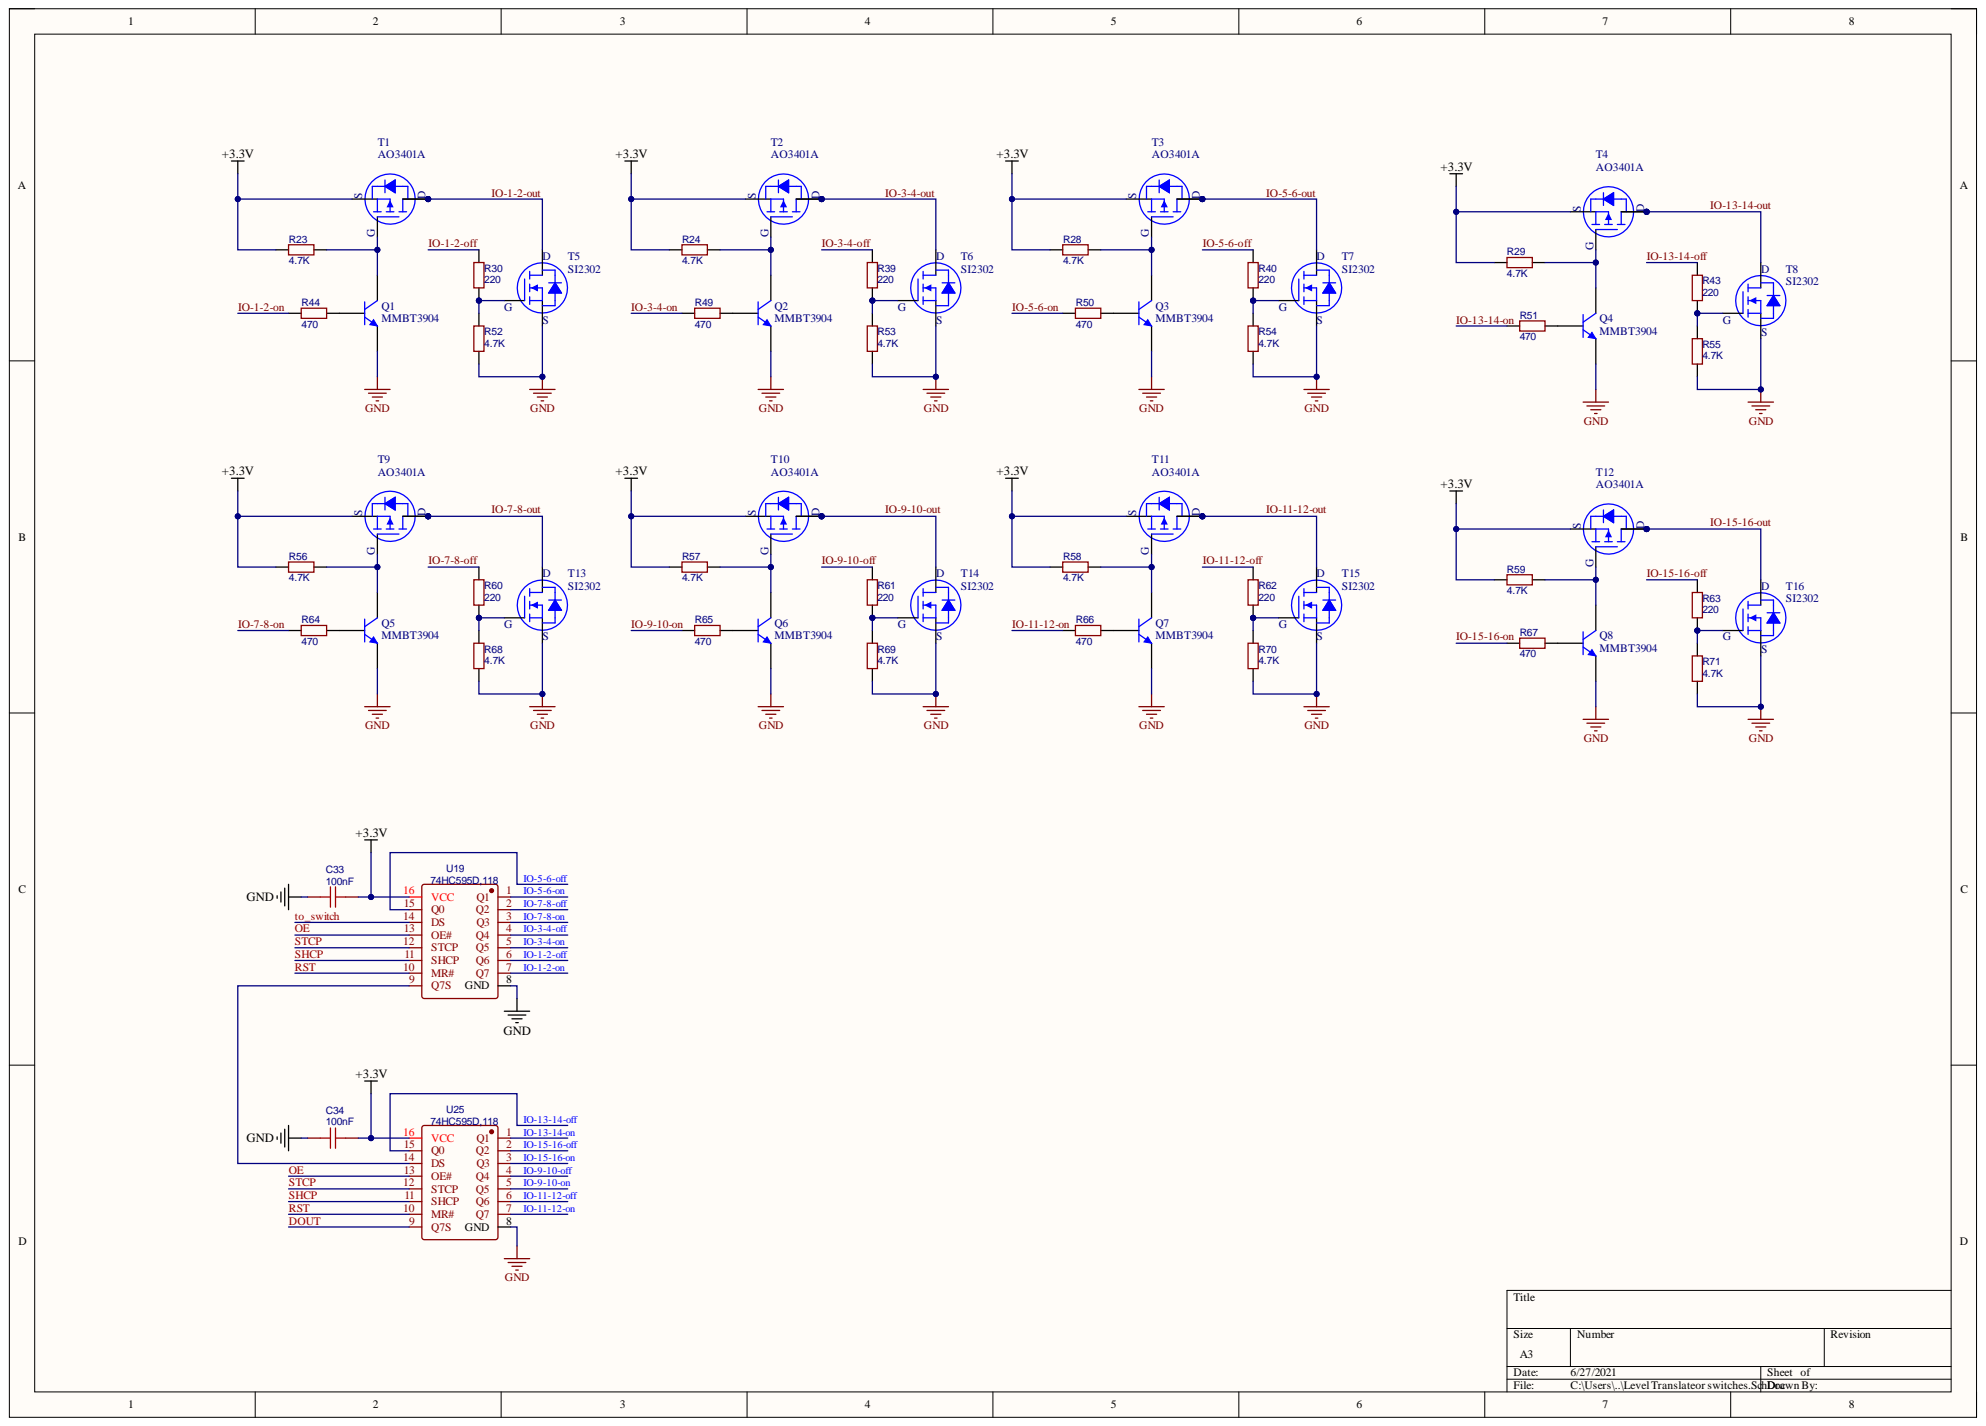
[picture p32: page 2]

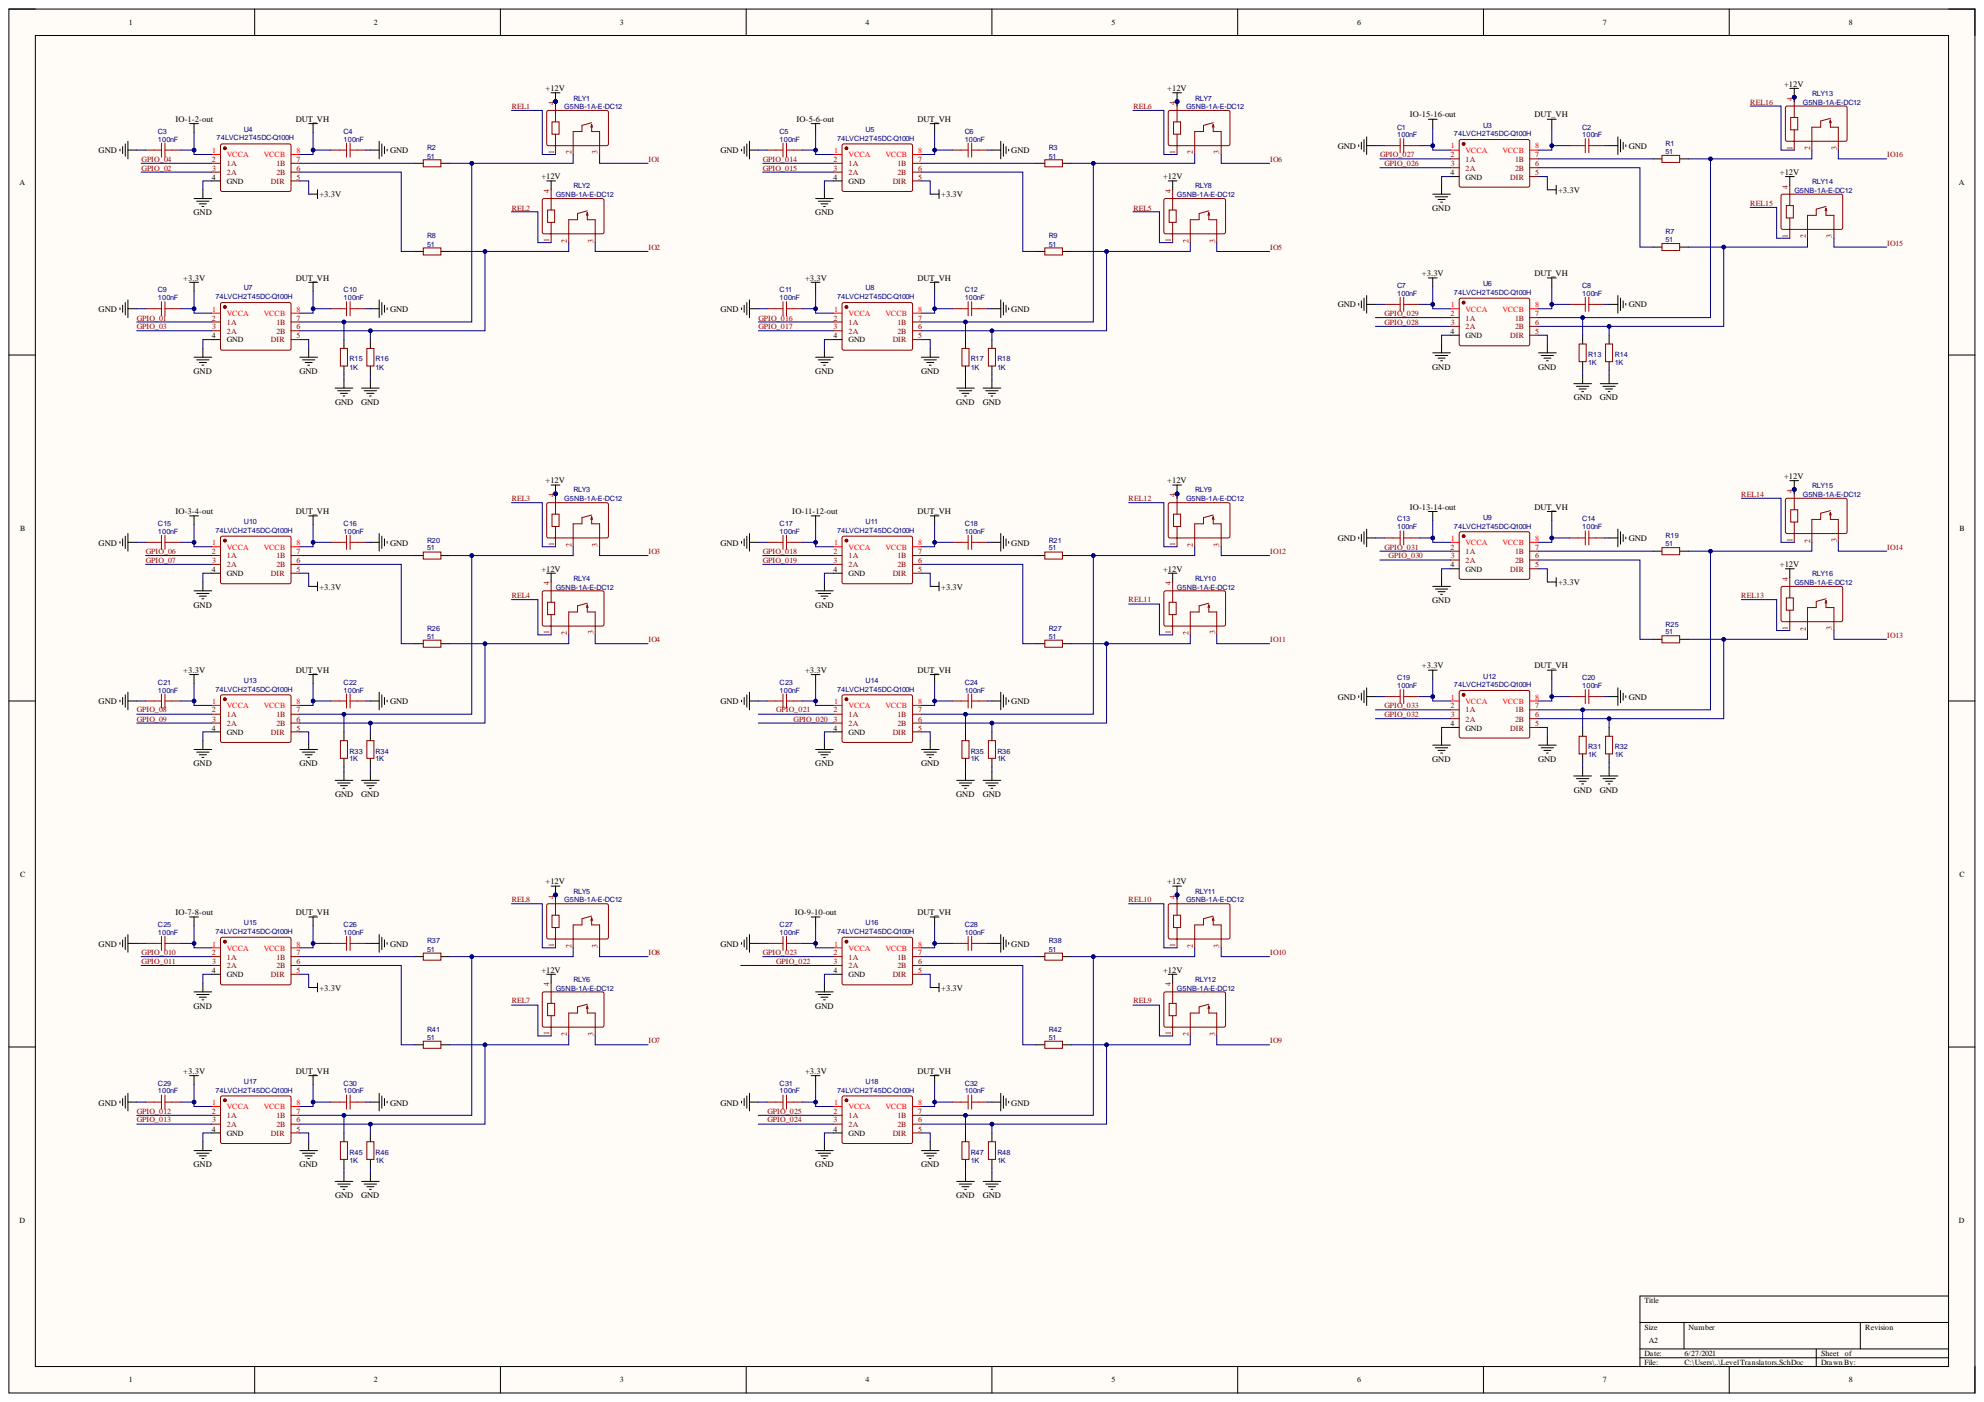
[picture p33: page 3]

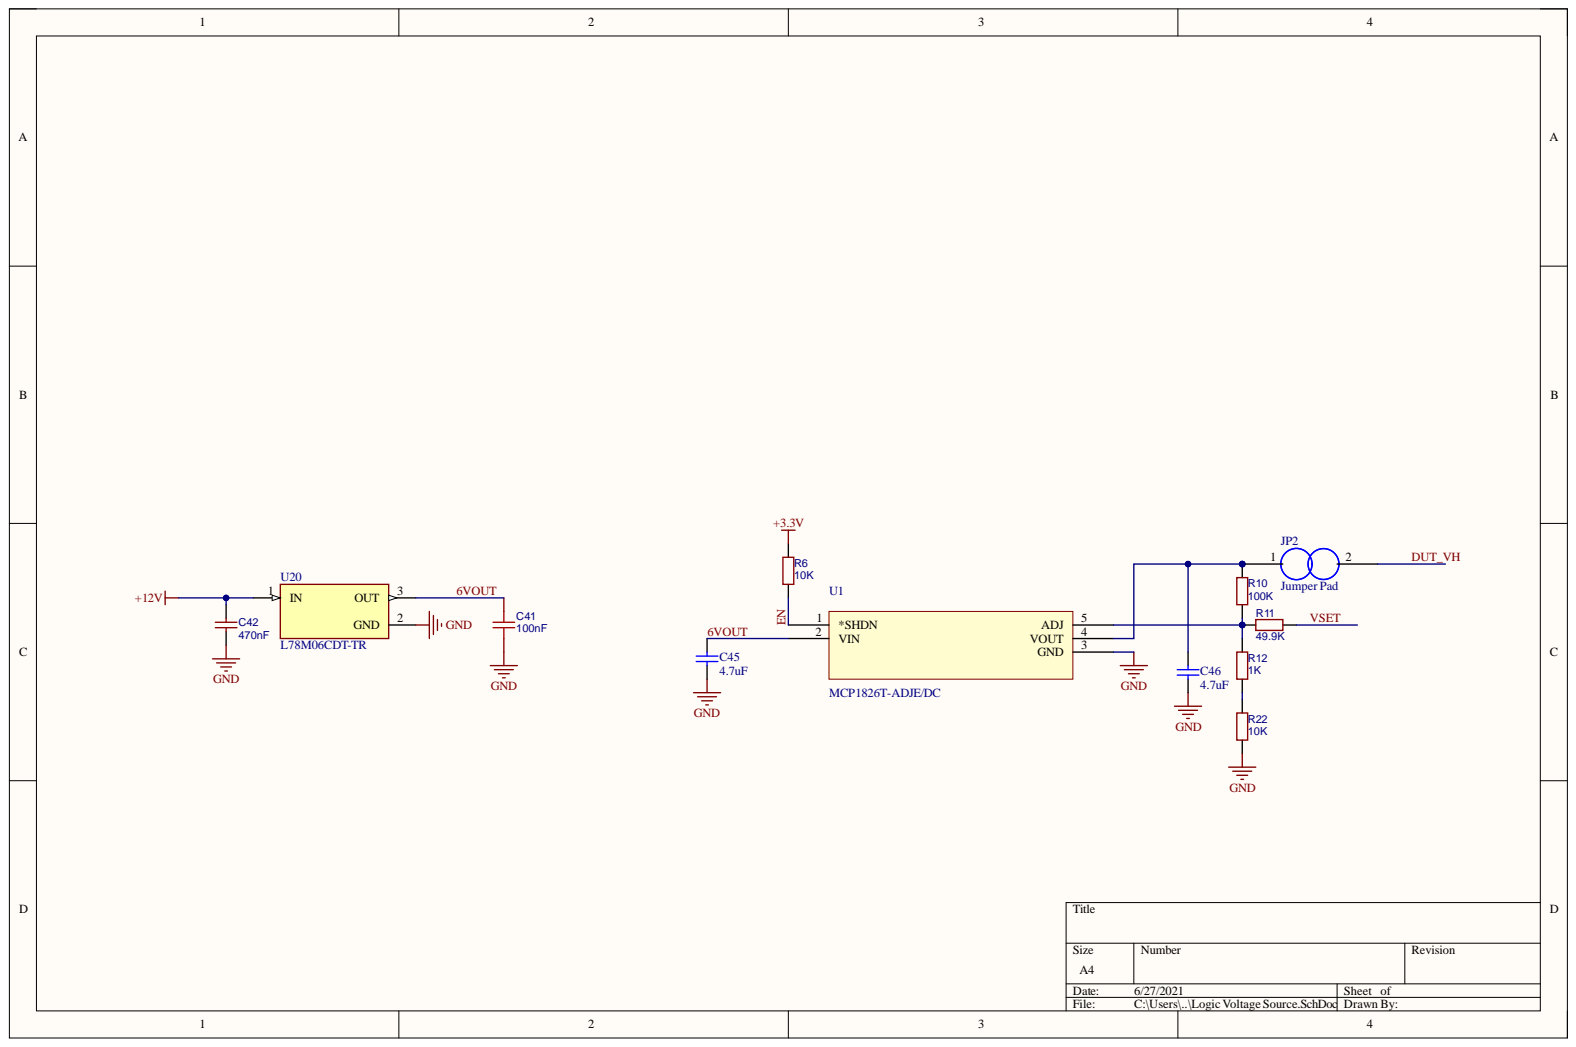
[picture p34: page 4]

Siz e A4 | Numb e r | R evisio n

Da te : 6/27/202 1 | She et of
File : C:\Use rs\. .\Logic Voltage Sour c e . S c hD o c | Dr awn By:

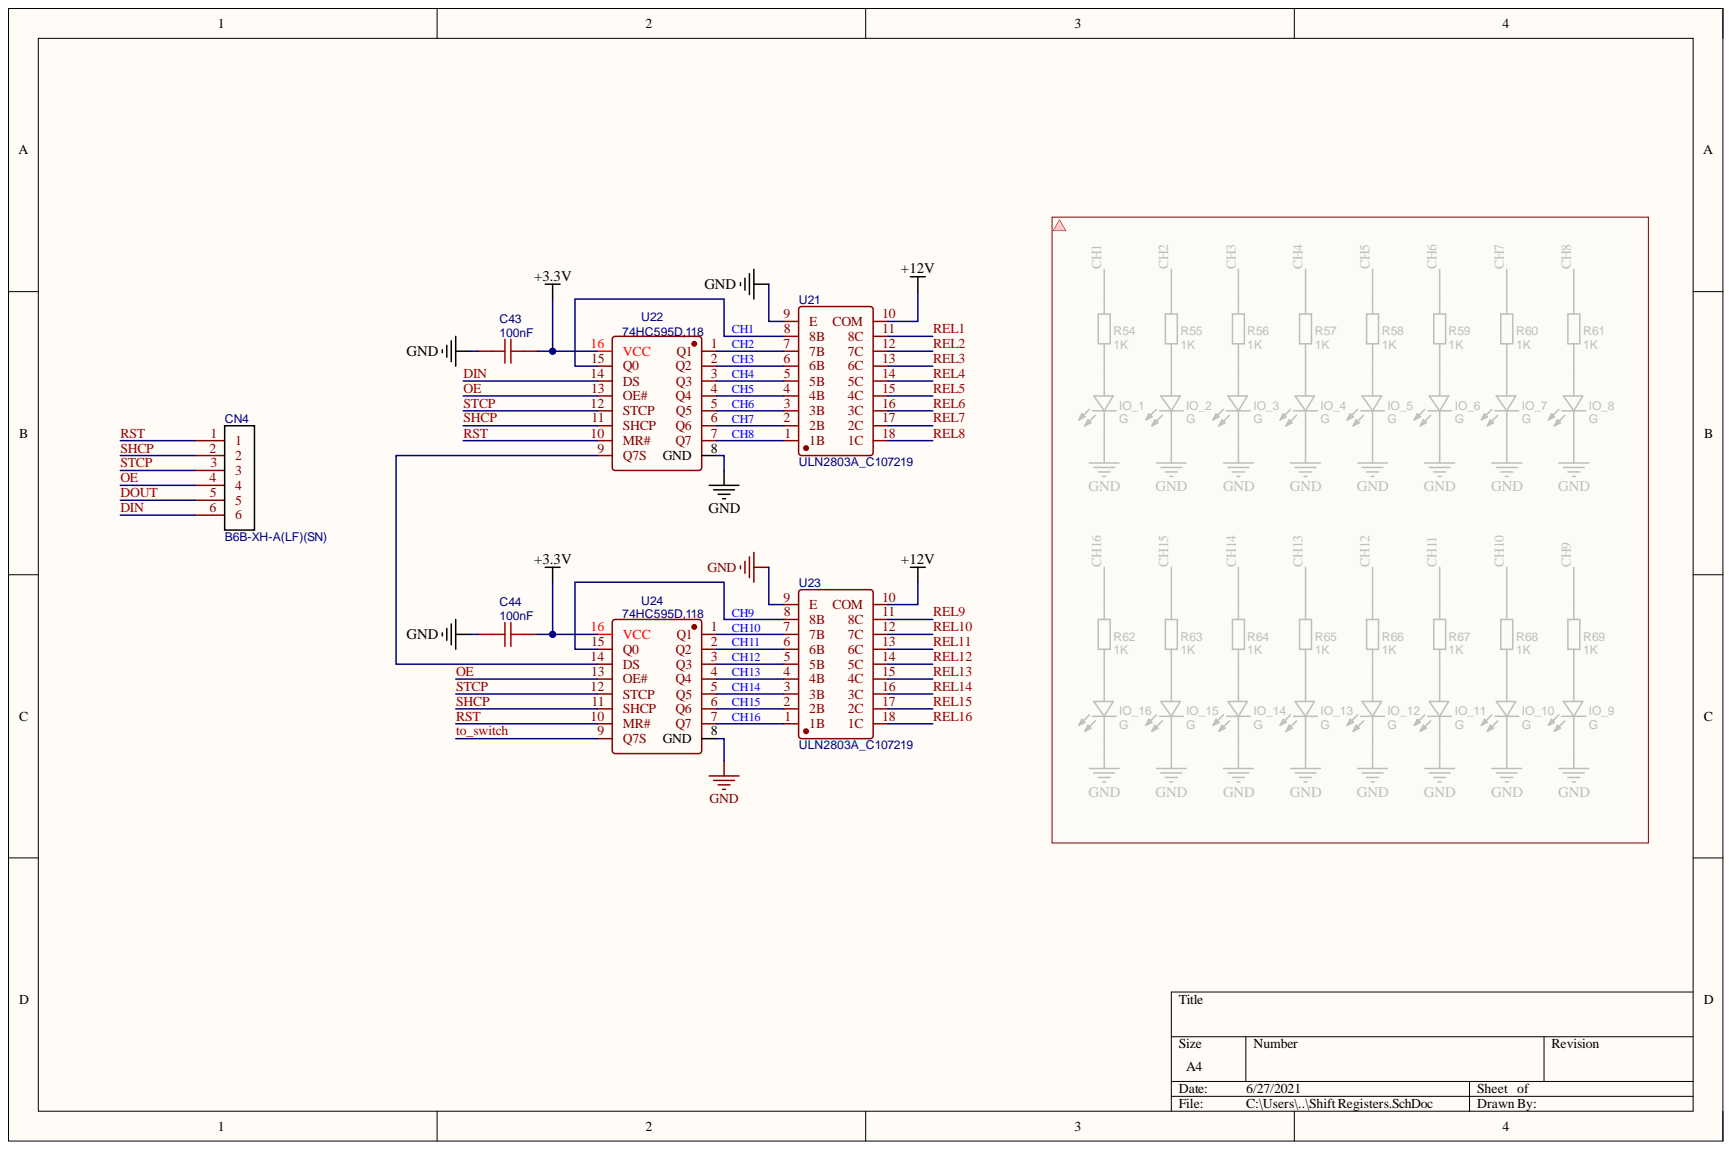
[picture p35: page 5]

Siz e A4 | Numb e r | R evisio n

Da te : 6/27/202 1 | She et of
File : C:\Use rs\. .\Shift R egiste rs. S c hD o c | Dr awn By:

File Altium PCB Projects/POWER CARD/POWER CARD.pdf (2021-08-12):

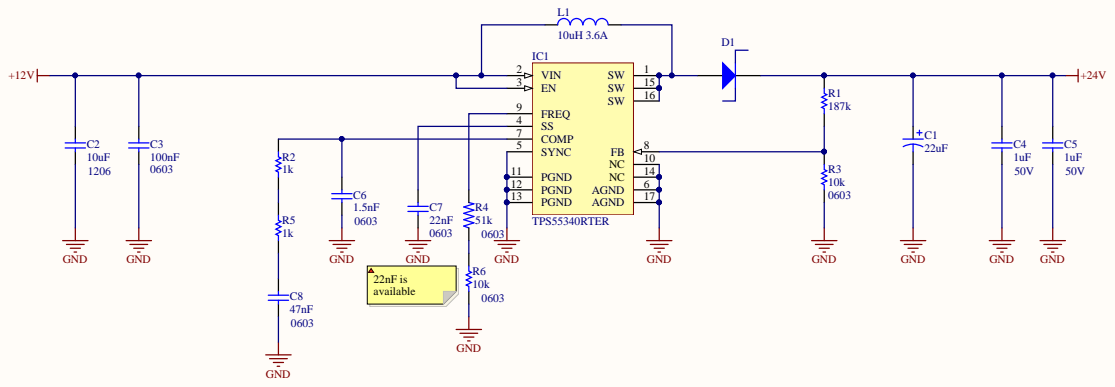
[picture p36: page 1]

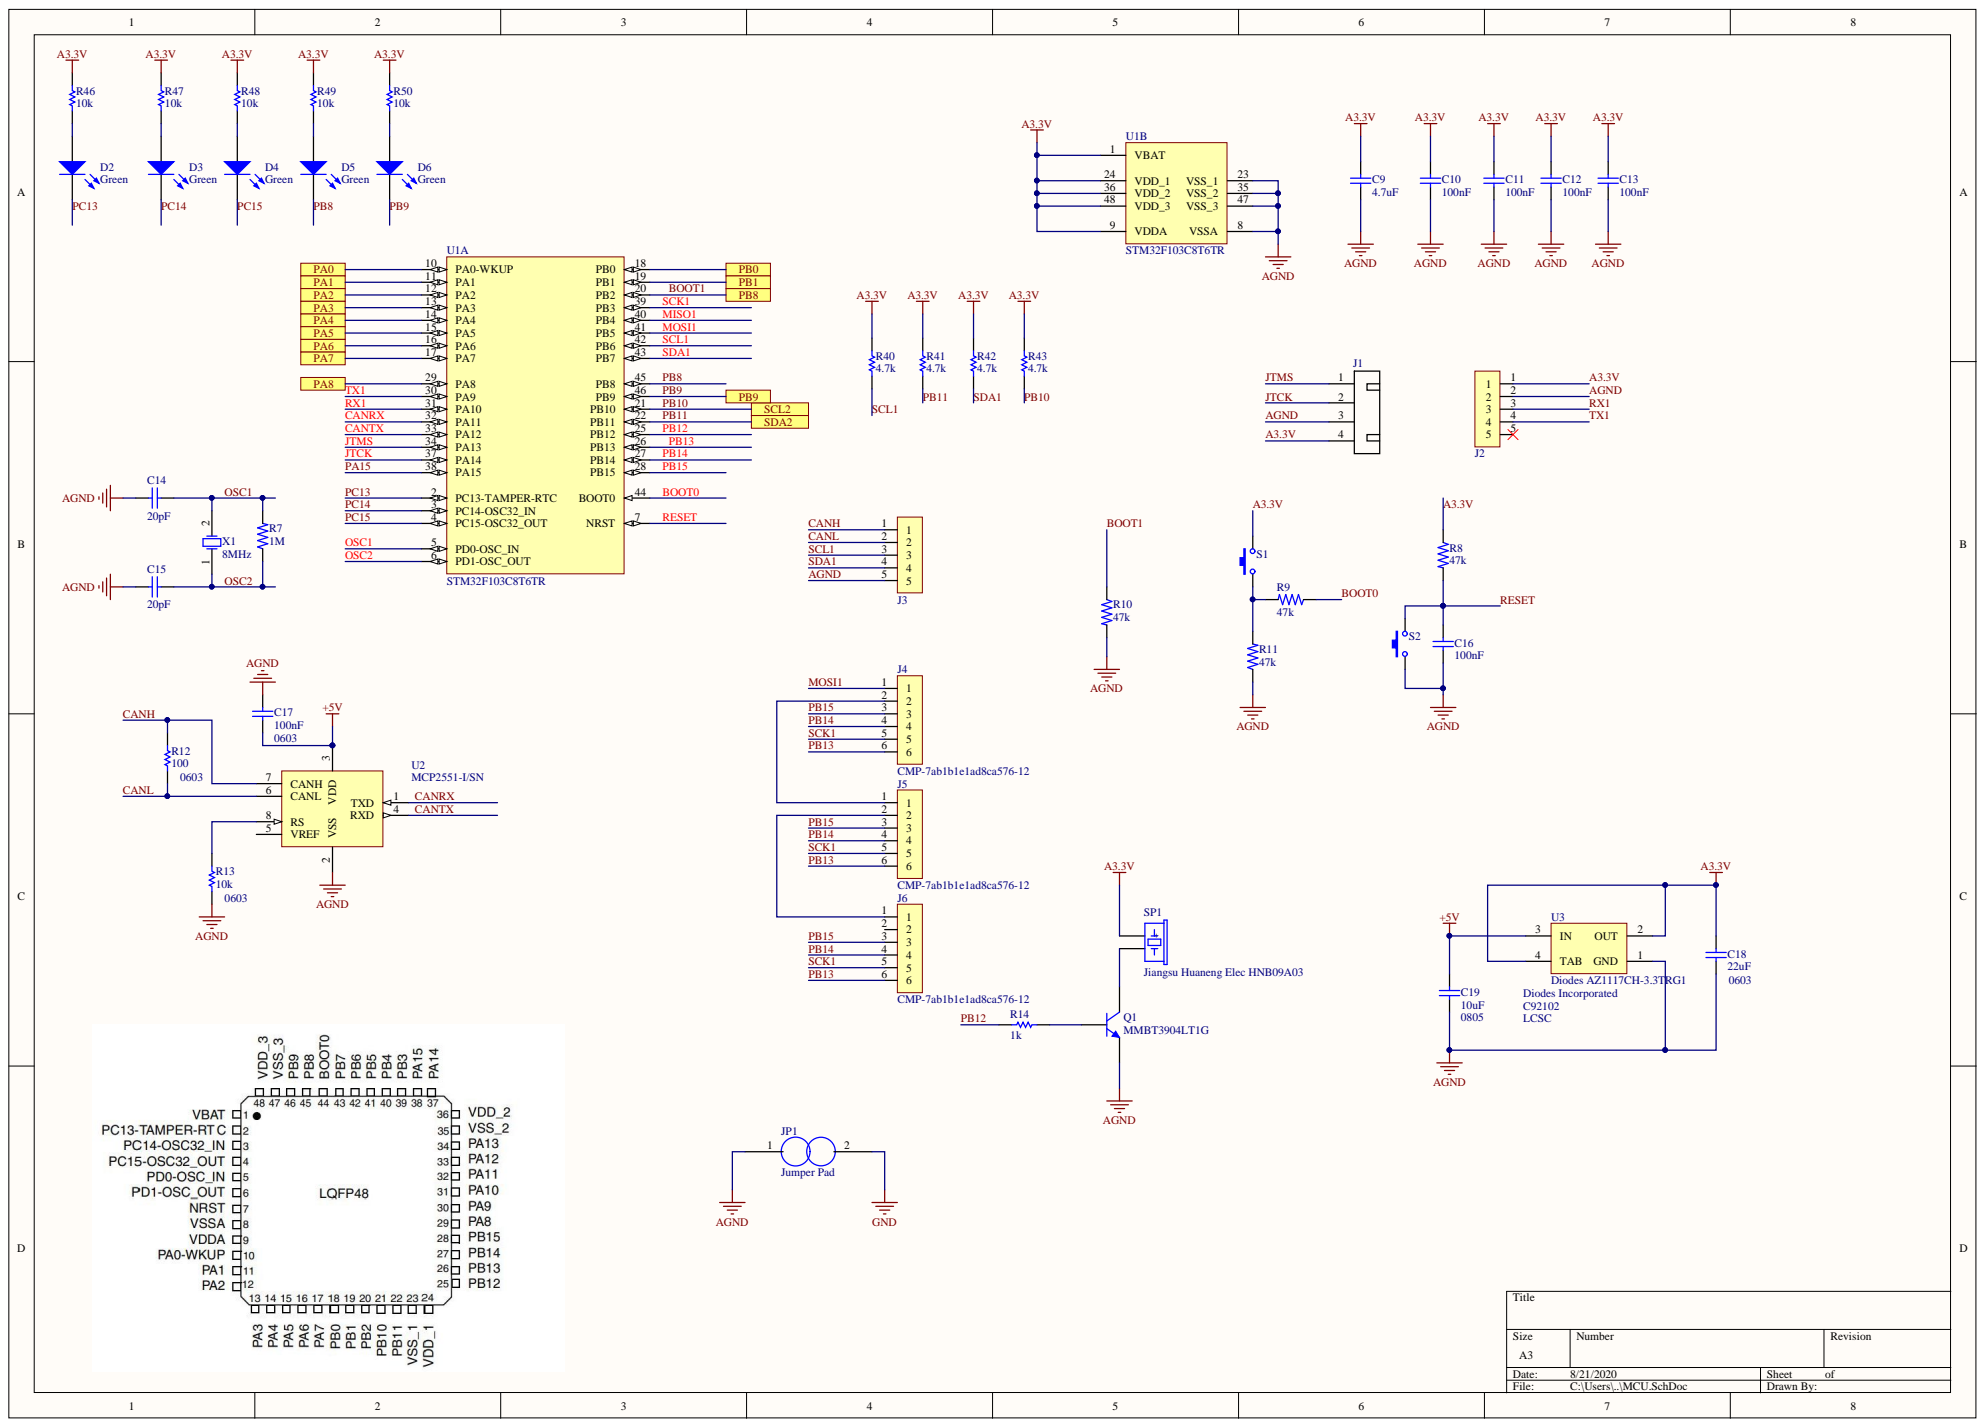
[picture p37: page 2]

PA6 | PA6 16 | SCL1
PA7 | PA7 17




10k | VREG5 3





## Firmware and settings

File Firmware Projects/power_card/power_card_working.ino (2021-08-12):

#include <Wire.h>
#include "defines.h"
#include "function_prototypes.h"

#define LED_D2 PC13
#define LED_D3 PC14
#define LED_D4 PC15
#define EN_1 PA0
#define ILIM_FB_1 PA1
#define ILIM_FB_2 PA2
#define LDAC_1 PA3
#define EN_2 PA4
#define RELAY_3 PA5
#define RELAY_2 PA6
#define RELAY_1 PA7
#define EN_3 PB0
#define ILIM_FB_3 PB1
#define LDAC_2 PB2
#define BUZZER PB12
#define RST PB13
#define STCP PB14
#define OE PB15
#define SHIFT_CLK PB3
#define SHIFT_DATA_PIN PB5
#define LED_D5 PB8
#define LED_D6 PB9





TwoWire Wire2 = TwoWire(PB11,PB10);

void setup() {
  // Timer for buzzer
  TIM_TypeDef *Instance = TIM1;
  HardwareTimer *MyTim = new HardwareTimer(Instance);
  MyTim->setOverflow(10, HERTZ_FORMAT); // 10 Hz
  MyTim->attachInterrupt(buzzer_callback);
  MyTim->resume();

  //IO declaration
  pinMode(LED_D2, OUTPUT);
  pinMode(LED_D3, OUTPUT);
  pinMode(LED_D4, OUTPUT);
  pinMode(EN_1, OUTPUT);
  pinMode(ILIM_FB_1, INPUT);
  pinMode(ILIM_FB_2, INPUT);
  pinMode(LDAC_1, OUTPUT);
  pinMode(EN_2, OUTPUT);
  pinMode(RELAY_3, OUTPUT);
  pinMode(RELAY_2, OUTPUT);
  pinMode(RELAY_1, OUTPUT);
  pinMode(EN_3, OUTPUT_OPEN_DRAIN);
  pinMode(ILIM_FB_3, INPUT);
  pinMode(BUZZER, OUTPUT);
  pinMode(RST, OUTPUT);
  pinMode(STCP, OUTPUT);
  pinMode(OE, OUTPUT);
  pinMode(SHIFT_CLK, OUTPUT);
  pinMode(SHIFT_DATA_PIN, OUTPUT);
  pinMode(LED_D5, OUTPUT);
  pinMode(LED_D6, OUTPUT);

  //startup logic for output pins
  digitalWrite(BUZZER,0);
  digitalWrite(LED_D4,0);
  digitalWrite(LED_D4,0);
  digitalWrite(LED_D6,0);
  digitalWrite(LED_D5,1);

  //iter_num = 0;
  startup();
  Serial1.println("Started");

  //tests

/*   enable_power_supply(PS2,ON);
  set_power_supply(PS2, 1000 - 100*(3000-3960)/107);  */
/*   enable_power_supply(PS1,ON);
  set_power_supply(PS1, 4*3300/5); */

  
/*   enable_power_supply(PS3,ON);
  set_power_supply(PS3,(11500/4)*(-1)+5150); //1400 3900 (5000*(-1/4))+5150 */
/* 
  set_current_source(3000+11+8);
  matrix_array[0] = 0b00110001;
  shiftOutAll(); */

/*
//matrix_array[0]=0b00100001; // uA
matrix_array[0]=0b01000010;//mA
matrix_array[10] = 0b01001010;//A9-PS1 5V
matrix_array[18] = 0b10000100;//A3 -GND
matrix_array[17] = 0b10000100;//A4 - GND
matrix_array[7]  = 0b10000100; // A12 - GND
//A10 and A11 to PS3
matrix_array[9] = 0b00010100;
matrix_array[8] = 0b00010100;
//A1 and A2 to PS2
matrix_array[20] = 0b00100100;
matrix_array[19] = 0b00100100;
//delay(5000);
shiftOutAll(); */

/* // HC595
//matrix_array[0] = 0b00000100; // nA
//matrix_array[0]=0b01000010;//mA
matrix_array[0]=0b00100001; // uA
matrix_array[4] = 0b01000100;
matrix_array[5] = 0b10000100;
matrix_array[6] = 0b10000100;
matrix_array[7] = 0b10000100;
matrix_array[8] = 0b10000100;
matrix_array[10] = 0b01001011;
matrix_array[13] = 0b10000100;
shiftOutAll(); */

}

void loop() 
{



  read_packet_status = read_packet_from_fifo();
  //delay(100);
  if(read_packet_status) execute_command();
  delay(10);
  
  //test

/*   matrix_array[10] = 0b01000100;
  shiftOutAll();
  delay(1000);
  matrix_array[10] = 0b00000000;
  shiftOutAll();
  delay(1000); */

}


/* 
// ################### HC595 ####################
matrix_array[0] = 0b00100001;
matrix_array[4] = 0b01000100;
matrix_array[5] = 0b10000100;
matrix_array[6] = 0b10000100;
matrix_array[7] = 0b10000100;
matrix_array[8] = 0b10000100;
matrix_array[10] = 0b01001011;
matrix_array[13] = 0b10000100;
shiftOutAll(); */

/* 
for(int i = 11; i < 21; i++)
{

  for(int j = 0; j < 8; j++)
  {
    matrix_array[i] = 1<<j;
    shiftOutAll();
    delay(500);
  }
  for(uint8_t k = 0; k <21; k++)
	{
		matrix_array[k] = 0b00000000; 
	}
 delay(1000);
} */

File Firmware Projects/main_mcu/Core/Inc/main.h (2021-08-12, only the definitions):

#define F_REQ_DONE_Pin GPIO_PIN_3
#define F_REQ_DONE_GPIO_Port GPIOC
#define F_PROCESS_REQ_Pin GPIO_PIN_1
#define F_PROCESS_REQ_GPIO_Port GPIOA
#define F_RST_Pin GPIO_PIN_2
#define F_RST_GPIO_Port GPIOA
#define F_CS0_Pin GPIO_PIN_3
#define F_CS0_GPIO_Port GPIOA
#define F_CS1_Pin GPIO_PIN_4
#define F_CS1_GPIO_Port GPIOA
#define F_SCK_Pin GPIO_PIN_5
#define F_SCK_GPIO_Port GPIOA
#define F_MISO_Pin GPIO_PIN_6
#define F_MISO_GPIO_Port GPIOA
#define F_MOSI_Pin GPIO_PIN_7
#define F_MOSI_GPIO_Port GPIOA
#define FLASH_CS_Pin GPIO_PIN_4
#define FLASH_CS_GPIO_Port GPIOC
#define F_REQ2_Pin GPIO_PIN_5
#define F_REQ2_GPIO_Port GPIOC
#define F_REQ1_Pin GPIO_PIN_0
#define F_REQ1_GPIO_Port GPIOB
#define F_REQ0_Pin GPIO_PIN_1
#define F_REQ0_GPIO_Port GPIOB
#define F_ADDR3_Pin GPIO_PIN_2
#define F_ADDR3_GPIO_Port GPIOB
#define F_ADDR2_Pin GPIO_PIN_11
#define F_ADDR2_GPIO_Port GPIOF
#define F_ADDR1_Pin GPIO_PIN_12
#define F_ADDR1_GPIO_Port GPIOF
#define F_ADDR0_Pin GPIO_PIN_13
#define F_ADDR0_GPIO_Port GPIOF
#define SH_RST_Pin GPIO_PIN_14
#define SH_RST_GPIO_Port GPIOF
#define LDAC_Pin GPIO_PIN_14
#define LDAC_GPIO_Port GPIOE
#define SHCP_Pin GPIO_PIN_13
#define SHCP_GPIO_Port GPIOB
#define DOUT_Pin GPIO_PIN_14
#define DOUT_GPIO_Port GPIOB
#define DIN_Pin GPIO_PIN_15
#define DIN_GPIO_Port GPIOB
#define STCP_Pin GPIO_PIN_8
#define STCP_GPIO_Port GPIOD
#define OE_Pin GPIO_PIN_9
#define OE_GPIO_Port GPIOD
#define CLKBUF_EN_Pin GPIO_PIN_2
#define CLKBUF_EN_GPIO_Port GPIOG
#define BUZZER_Pin GPIO_PIN_8
#define BUZZER_GPIO_Port GPIOG
#define LED1_Pin GPIO_PIN_6
#define LED1_GPIO_Port GPIOC
#define LED2_Pin GPIO_PIN_7
#define LED2_GPIO_Port GPIOC
#define LED3_Pin GPIO_PIN_8
#define LED3_GPIO_Port GPIOC
#define LED4_Pin GPIO_PIN_9
#define LED4_GPIO_Port GPIOC
#define LED5_Pin GPIO_PIN_8
#define LED5_GPIO_Port GPIOA
#define LED6_Pin GPIO_PIN_15
#define LED6_GPIO_Port GPIOA
#define LED7_Pin GPIO_PIN_10
#define LED7_GPIO_Port GPIOC
#define LED8_Pin GPIO_PIN_11
#define LED8_GPIO_Port GPIOC
#define SW1_Pin GPIO_PIN_12
#define SW1_GPIO_Port GPIOC
#define SW3_Pin GPIO_PIN_0
#define SW3_GPIO_Port GPIOD
#define SW2_Pin GPIO_PIN_1
#define SW2_GPIO_Port GPIOD
#define SW4_Pin GPIO_PIN_2
#define SW4_GPIO_Port GPIOD
#define new_ic_switch_Pin GPIO_PIN_9
#define new_ic_switch_GPIO_Port GPIOG
#define LED_STM_Pin GPIO_PIN_15
#define LED_STM_GPIO_Port GPIOG
#define PW_CARD_RESET_Pin GPIO_PIN_9
#define PW_CARD_RESET_GPIO_Port GPIOB

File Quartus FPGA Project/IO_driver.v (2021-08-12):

module IO_driver(
	input		      s_clk,
	input			  c_clk,
	input             reset,
	//SPI related 
	input 		      MOSI,
	output            MISO,
	input		      SCK,
	input [1:0]	      CS_addr,

	input [3:0]  	  addr,          // Address of a io pin driver (source fifo + capture fifo)
	input [2:0]		  request,       //1-spi_wrreq, 2-spi_rdreq, 3-copy_from_spi_req, 4-copy_to_spi_req, 5-exe_start, 6-clock_output
	input 			  process_rqst,
	input [15:0] 	  io_capture_pins,
	output[15:0]      io_source_pins,

	output 	 req_done,     // indicate that a copy operation is done

	//for testing
	output [1:0] state_indication,
	output s_clock_probe,
	output c_clock_probe
);
// wire clk1;
// reg [5:0] clock_div = 0;
// always @ (posedge clk)begin
// 	clock_div <= clock_div +1;
// end
// assign clk1 = clock_div[0];
// assign clk1 = s_clk;
assign s_clock_probe = s_clk;
assign c_clock_probe = c_clk;


parameter FPGA_ADDR = 2;
wire CS;
assign CS = (CS_addr == FPGA_ADDR)? 1:0;
//tri state buffers for outputs to MCU
reg	 req_done_flag;
wire MISO_bufin;
bufif1 req_done_buf(req_done, req_done_flag, CS);
bufif1 MISO_buf(MISO,MISO_bufin,CS); 

//Chip Selected signals (ie. to make CS the FPGA enable)
wire SCK_CS;
assign SCK_CS = (CS)? SCK : 0;

wire spi_wrreq_CS;
wire spi_rdreq_CS;
reg copy_from_spi_req_CS;
reg copy_to_spi_req_CS;
reg exe_start;


assign spi_wrreq_CS  = (CS && (request == 1))? 1 : 0;
assign spi_rdreq_CS  = (CS && (request == 2))? 1 : 0;


//for execution start condition
reg [15:0] exe_start_flags;
reg [15:0] capture_start_flags;

//connection to clear all FIFOs
wire aclr;
assign aclr = ~reset;

//multiplexers for clock outputs
reg[15:0] io_clk_source_en;
wire[15:0] source_fifo_outputs;

assign io_source_pins[0] = (io_clk_source_en[0])? s_clk :source_fifo_outputs[0];
assign io_source_pins[1] = (io_clk_source_en[1])? s_clk :source_fifo_outputs[1];
assign io_source_pins[2] = (io_clk_source_en[2])? s_clk :source_fifo_outputs[2];
assign io_source_pins[3] = (io_clk_source_en[3])? s_clk :source_fifo_outputs[3];
assign io_source_pins[4] = (io_clk_source_en[4])? s_clk :source_fifo_outputs[4];
assign io_source_pins[5] = (io_clk_source_en[5])? s_clk :source_fifo_outputs[5];
assign io_source_pins[6] = (io_clk_source_en[6])? s_clk :source_fifo_outputs[6];
assign io_source_pins[7] = (io_clk_source_en[7])? s_clk :source_fifo_outputs[7];
assign io_source_pins[8] = (io_clk_source_en[8])? s_clk :source_fifo_outputs[8];
assign io_source_pins[9] = (io_clk_source_en[9])? s_clk :source_fifo_outputs[9];
assign io_source_pins[10] = (io_clk_source_en[10])? s_clk :source_fifo_outputs[10];
assign io_source_pins[11] = (io_clk_source_en[11])? s_clk :source_fifo_outputs[11];
assign io_source_pins[12] = (io_clk_source_en[12])? s_clk :source_fifo_outputs[12];
assign io_source_pins[13] = (io_clk_source_en[13])? s_clk :source_fifo_outputs[13];
assign io_source_pins[14] = (io_clk_source_en[14])? s_clk :source_fifo_outputs[14];
assign io_source_pins[15] = (io_clk_source_en[15])? s_clk :source_fifo_outputs[15];


/*##################### MOSI FIFO to SOURCE FIFOs  ######################*/
//spi_mosi_fifo_connections
wire spi_mosi_fifo_rdempty;
wire spi_mosi_fifo_rdreq;
wire spi_mosi_fifo_q;
reg copy_from_spi_flag;
assign spi_mosi_fifo_rdreq = copy_from_spi_flag & (~spi_mosi_fifo_rdempty);

//source_fifo1 to source_fifo16 connections
reg [15:0] source_fifo_wrreq;
wire[15:0] source_fifo_rdreq;
wire[15:0] source_fifo_rdempty;
assign source_fifo_rdreq = exe_start_flags & (~source_fifo_rdempty);

/*##################### CAPTURE FIFOs to MISO FIFO  #####################*/
//spi_miso_fifo_connections
reg spi_miso_fifo_data;
reg spi_miso_fifo_wrreq;
reg copy_to_spi_flag;

//capture_fifo1 to capture_fifo16 connections
wire [15:0] capture_fifo_rdreq;
wire [15:0] capture_fifo_empty;
wire [15:0] capture_fifo_q;
wire 		capture_fifo_wrreq;
assign capture_fifo_wrreq = (capture_start_flags == 0)? 0:1;

//state variable
reg [1:0] state;
assign state_indication = state;

/*################ MULTIPLEXERS and DEMULTIPLEXERS ######################*/

//source_fifo write request DEMUX
// assign source_fifo_wrreq[0]  = (addr == 0)? spi_mosi_fifo_rdreq : 0; 
// assign source_fifo_wrreq[1]  = (addr == 1)? spi_mosi_fifo_rdreq : 0;
// assign source_fifo_wrreq[2]  = (addr == 2)? spi_mosi_fifo_rdreq : 0;
// assign source_fifo_wrreq[3]  = (addr == 3)? spi_mosi_fifo_rdreq : 0;
// assign source_fifo_wrreq[4]  = (addr == 4)? spi_mosi_fifo_rdreq : 0;
// assign source_fifo_wrreq[5]  = (addr == 5)? spi_mosi_fifo_rdreq : 0;
// assign source_fifo_wrreq[6]  = (addr == 6)? spi_mosi_fifo_rdreq : 0;
// assign source_fifo_wrreq[7]  = (addr == 7)? spi_mosi_fifo_rdreq : 0;
// assign source_fifo_wrreq[8]  = (addr == 8)? spi_mosi_fifo_rdreq : 0;
// assign source_fifo_wrreq[9]  = (addr == 9)? spi_mosi_fifo_rdreq : 0;
// assign source_fifo_wrreq[10] = (addr ==10)? spi_mosi_fifo_rdreq : 0;
// assign source_fifo_wrreq[11] = (addr ==11)? spi_mosi_fifo_rdreq : 0;
// assign source_fifo_wrreq[12] = (addr ==12)? spi_mosi_fifo_rdreq : 0;
// assign source_fifo_wrreq[13] = (addr ==13)? spi_mosi_fifo_rdreq : 0;
// assign source_fifo_wrreq[14] = (addr ==14)? spi_mosi_fifo_rdreq : 0;
// assign source_fifo_wrreq[15] = (addr ==15)? spi_mosi_fifo_rdreq : 0;

//spi_miso_fifo_wrreq signal
// always @(*) begin
// 	case(addr)
// 		0:  spi_miso_fifo_wrreq = copy_to_spi_flag & capture_fifo_empty[0]; 
// 		1:  spi_miso_fifo_wrreq = copy_to_spi_flag & capture_fifo_empty[1];
// 		2:  spi_miso_fifo_wrreq = copy_to_spi_flag & capture_fifo_empty[2];
// 		3:  spi_miso_fifo_wrreq = copy_to_spi_flag & capture_fifo_empty[3];
// 		4:  spi_miso_fifo_wrreq = copy_to_spi_flag & capture_fifo_empty[4];
// 		5:  spi_miso_fifo_wrreq = copy_to_spi_flag & capture_fifo_empty[5];
// 		6:  spi_miso_fifo_wrreq = copy_to_spi_flag & capture_fifo_empty[6];
// 		7:  spi_miso_fifo_wrreq = copy_to_spi_flag & capture_fifo_empty[7];
// 		8:  spi_miso_fifo_wrreq = copy_to_spi_flag & capture_fifo_empty[8];
// 		9:  spi_miso_fifo_wrreq = copy_to_spi_flag & capture_fifo_empty[9];
// 		10: spi_miso_fifo_wrreq = copy_to_spi_flag & capture_fifo_empty[10];
// 		11: spi_miso_fifo_wrreq = copy_to_spi_flag & capture_fifo_empty[11];
// 		12: spi_miso_fifo_wrreq = copy_to_spi_flag & capture_fifo_empty[12];
// 		13: spi_miso_fifo_wrreq = copy_to_spi_flag & capture_fifo_empty[13];
// 		14: spi_miso_fifo_wrreq = copy_to_spi_flag & capture_fifo_empty[14];
// 		15: spi_miso_fifo_wrreq = copy_to_spi_flag & capture_fifo_empty[15];
// 	endcase
// end
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

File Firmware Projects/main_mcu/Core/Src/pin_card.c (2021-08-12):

/*
 * pin_card.c
 *
 *  Created on: Jan 18, 2021
 *      Author: Thilina
 */
#include "pin_card.h"
#define DEBUG_REQUEST_FROM_PIN_CARD

void request_from_pin_card(){
    /*    ----------------------------------------------------------
      |  0   |   1   |    2      |   3 4 5 6  |    7 8          |   9   |
      ----------------------------------------------------------
      |  S   |   ID  |  COMMAND  |  VALUE     |   PAYLOAD_SIZE  |   E   |
      ----------------------------------------------------------
*/
	//request from PIN_CARD_A
	if(num_req_A > 0)
	{
		request_status = HAL_I2C_Master_Receive(&hi2c1, PIN_CARD_A_ADDR<<1, header_to_ui, 10, 100);
		header_to_ui[1] = pincardA;
		if((header_to_ui[2] == measure_I)||(header_to_ui[2] == measure_V))
		{
			while(CDC_Transmit_FS(header_to_ui, 10));
			num_req_A --;
			//print("Measurement Received\n");
		}
		else if(header_to_ui[2] == 0xAA)
		{
			//print("Slave BUSY\n");
		}
		else if(header_to_ui[2] == 0xBB)
		{
			//print("SLAVE BUFFER EMPTY");
		}

		print("REQUEST status PINCARD_A %d\n",request_status);
		for(int i = 0; i < 10; i++)
		{
			print("%d ",header_to_ui[i]);
		}
		print("\n");

	}
	//Requests from pincard B
	else if(num_req_B > 0)
	{
		request_status = HAL_I2C_Master_Receive(&hi2c1, PIN_CARD_B_ADDR<<1, header_to_ui, 10, 100);
		header_to_ui[1] = pincardB;
		if((header_to_ui[2] == measure_I)||(header_to_ui[2] == measure_V))
		{
			while(CDC_Transmit_FS(header_to_ui, 10));
			num_req_B --;
			//print("Measurement Received\n");
		}
		else if(header_to_ui[2] == 0xAA)
		{
			//print("Slave BUSY\n");
		}
		else if(header_to_ui[2] == 0xBB)
		{
			//print("SLAVE BUFFER EMPTY");
		}

		print("REQUEST status PINCARD_A %d\n",request_status);
		for(int i = 0; i < 10; i++)
		{
			print("%d ",header_to_ui[i]);
		}
		print("\n");

	}
	else
	{
		notify_new_ic = 0;
		request_from_pincard = 0;
		read_from_ui = 1;

	}

	//request from PIN_CARD_B
/*	if(request_B)
	{
		lrt_B = crt_B;
		request_status = HAL_I2C_Master_Receive(&hi2c1, PIN_CARD_B_ADDR<<1, collected_data_B, 10, 100);

		if(collected_data_B[2]!=0)
		{
			while(CDC_Transmit_FS(collected_data_B, 10));
			num_req_B --;
		}
	}*/

}

uint8_t decode_packet()
{
	/*    --------------------------------------------------------------
			  |  0   | 1  |    2    |   3 4 5 6  |     7 8         |   9   |
			  --------------------------------------------------------------
			  |  S   | ID |COMMAND  |  VALUE     |   PAYLOAD_SIZE  |   E   |
			  ---------------------------------------------------------------*/

	//device, command, value, payload_size

	uint8_t e = 0; // error flag

	if(packet[1] == pincardA) // To PINCARD_A
	{

		packet[1] = packet[0];

		e = HAL_I2C_Master_Transmit(&hi2c1, PIN_CARD_A_ADDR<<1, &packet[1], packet_size -1, 100);
		HAL_Delay(1);

		//counting measure packets
		if((packet[2] == measure_V) || (packet[2] == measure_I))
		{
			num_req_A ++;
		}
	}
	else if(packet[1] == pincardB) // To PINCARD_B
	{
		packet[1] = packet[0];
		e = HAL_I2C_Master_Transmit(&hi2c1, PIN_CARD_B_ADDR<<1, &packet[1], packet_size-1, 100);
		//HAL_I2C_Master_Transmit(&hi2c1, PIN_CARD_B_ADDR<<1, &packet[2], packet_size - 2, 100);
		HAL_Delay(1);

		//counting measure packets
		if((packet[2] == measure_V) || (packet[2] == measure_I))
		{
			num_req_B ++;
		}
	}

	else if(device == io)
	{
		if( command == start_digital_tests)
		{
			//###################
			beep(3);
		}

		else if(command == execute_sourcing)
		{
			//configure relay and level shifters
			f_shiftOutAll();

			//Execute test
			f_request(EXE_START);
			f_request(NO_REQ);
			HAL_Delay(1);
			while(HAL_GPIO_ReadPin(F_REQ_DONE_GPIO_Port, F_REQ_DONE_Pin)== 0);

			//reset relay and level shifters
			f_matrix_init();
		}
		else if( command == reset_io_drivers)
		{
			f_reset();

		}
		else if(command == set_fpga_frequency)
		{
			f_set_frequency(value);
		}
		else if(command = set_io_voltage )
		{
			f_set_io_voltage(-value+5300);
		}


	}

	else if( (device >= io1) && (device <= io48) )
	{
		if(device <= io16) f_cs(1);
		else if(device <= io32) f_cs(2);
		else if(device <= io48) f_cs(3);

		if(command == load_source_vector)
		{
			//set data to iox
			f_request(SPI_WRREQ);
			HAL_SPI_Transmit(&hspi1, &packet[10], payload_size, HAL_MAX_DELAY);
			f_request(NO_REQ);
			HAL_SPI_Transmit(&hspi1, null_byte, 1, 10);

			f_address(device - 16); // io1 --> address 0
			f_request(COPY_FROM_SPI);
			f_request(NO_REQ);
			//HAL_Delay(1);
			while(HAL_GPIO_ReadPin(F_REQ_DONE_GPIO_Port, F_REQ_DONE_Pin)== 0);
		}

		else if(command == read_capture_vector)
		{
			//read from iox to spi fifo begin
			f_address(device-16);
			f_request(COPY_TO_SPI);
			f_request(NO_REQ);
			HAL_Delay(1);
			while(HAL_GPIO_ReadPin(F_REQ_DONE_GPIO_Port, F_REQ_DONE_Pin)== 0);

			//before read request, a null byte should be sent
			HAL_SPI_Transmit(&hspi1, null_byte, 1, 10);
			f_request(SPI_RDREQ);
			HAL_SPI_Receive(&hspi1, &fdata_to_ui[10], value, HAL_MAX_DELAY);
			f_request(NO_REQ);
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

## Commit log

2021-08-12 fpga codes
    [IO_driver.smp_dump.txt]
2021-08-12 fpga project name change
    [IO_driver.smp_dump.txt]
2021-08-12 firmware, software exe, documents
    [shift array definitions.xlsx]

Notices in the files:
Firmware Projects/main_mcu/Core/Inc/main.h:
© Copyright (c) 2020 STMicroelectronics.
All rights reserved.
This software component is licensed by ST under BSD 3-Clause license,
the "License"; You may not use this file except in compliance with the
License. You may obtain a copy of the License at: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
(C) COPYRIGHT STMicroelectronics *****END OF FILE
